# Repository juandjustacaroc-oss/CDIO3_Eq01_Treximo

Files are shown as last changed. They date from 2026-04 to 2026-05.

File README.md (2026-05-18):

# CDIO3_Eq01_Treximo: Smart Athletic Timing & Physiological Monitoring System
Sistema distribuido basado en ESP32 para cronometraje automático y monitoreo fisiológico en pruebas de atletismo (100 m), diseñado para proporcionar mediciones precisas de tiempo, velocidad y frecuencia cardíaca en tiempo real. Este proyecto integra comunicación inalámbrica de baja latencia, procesamiento embebido y una interfaz web ligera para ofrecer retroalimentación inmediata al entrenador sin depender de infraestructura externa o servicios en la nube.



# Objetivo del Proyecto
Desarrollar un sistema portátil y autónomo capaz de:
- Detectar automáticamente el inicio y finalización de la carrera.
- Calcular el tiempo exacto del recorrido.
- Estimar la velocidad promedio del atleta.
- Monitorear la frecuencia cardíaca durante la carrera y la fase de recuperación.
- Visualizar métricas en pantalla OLED y en una interfaz web básica embebida.
- Reiniciar el sistema de forma segura para múltiples sesiones consecutivas.

# Arquitectura General
- Peon Salida/Peon Llegada.
- Cerebro Cronometro.
- Banda de variables fisiologicas.
La comunicación entre nodos se realiza mediante ESP-NOW.
El nodo central también opera como punto de acceso WiFi para permitir la visualización de datos desde un smartphone o tablet.

# Estado Actual [MAHD](https://docs.google.com/spreadsheets/d/1o7weHOlPSlPQWPbzmIAxRxXA6ihxt1Q-x_elVm5SotQ/edit?usp=sharing) 
- ✅Hardware funcional
- ✅Comunicación estable entre nodos
- ✅Cronometría precisa basada en eventos
- ❌Monitoreo cardíaco integrado
- ✅Interfaz TFT operativa
- ✅Dashboard web ligero en pruebas

# Librerías necesarias

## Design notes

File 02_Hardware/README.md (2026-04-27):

# Hardware

## Diseño y Arquitectura Física del Sistema

Esta carpeta contiene todos los recursos asociados al desarrollo físico y electrónico del sistema distribuido basado en ESP32.

El hardware está dividido en tres subsistemas principales:

- 🧠 Cronómetro Central
- 📡 Peones (Salida y Llegada)
- ❤️ Banda de Variables Fisiológicas

---

## Estructura de Carpetas

### 📂 Datasheets/
Contiene únicamente hojas técnicas oficiales (PDF) de los componentes utilizados:
- ESP32
- UWB (DW1000 / RYUW122)
- MAX3010x
- RTC
- Pantalla TFT
- Módulos de carga
- Sensores ultrasónicos

Estos documentos fundamentan las decisiones técnicas adoptadas en el diseño.

---

### 📂 Mechanical/
Archivos mecánicos del proyecto:
- STL (impresión 3D)
- DXF (corte láser)
- CAD (modelos completos)

Incluye:
- Carcasa del cronómetro
- Soportes de peones
- Integración de banda fisiológica

---

### 📂 Source/
Archivos editables de diseño electrónico:
- KiCad
- Altium
- Eagle

Contiene:
- Esquemáticos
- PCB
- Layout
- Gerbers (si aplica)

---

## Consideraciones Técnicas

- Alimentación autónoma con sistema de carga y protección.
- Comunicación inalámbrica UWB para medición de distancia.
- ESP-NOW para eventos críticos de cronometraje.
- Diseño modular para mantenimiento y escalabilidad.

---

## Estado

El hardware ha sido auditado y actualizado tras la revisión técnica del diseño inicial.
Las modificaciones están justificadas en la Matriz de Defensa de Diseño (ver carpeta 01_Gestion).

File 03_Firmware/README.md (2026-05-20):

# 03_Firmware — Firmware ESP32 TRÉXIMO

Esta carpeta contiene el firmware de los nodos ESP32 que conforman el sistema **TRÉXIMO**.

El firmware implementa:
- detección de eventos,
- cronometraje,
- comunicación inalámbrica,
- cálculo de variables deportivas,
- integración con la aplicación web,
- y gestión de estados del sistema.

---

# Nodos del sistema

| Nodo | Función | Archivo esperado |
|---|---|---|
| Cerebro / Cronómetro | Recibe eventos, calcula tiempo y velocidad, y envía datos a la aplicación | `CerebroFinal_*.ino` |
| Peón salida | Detecta salida mediante HC-SR04 y envía evento `START` | `Peon_Salida_*.ino` |
| Peón llegada | Detecta llegada mediante HC-SR04 y envía evento `FINISH` | `Peon_Llegada_*.ino` |
| Simulador ESP32 | Genera carreras aleatorias para pruebas de backend/app | `ESP32_Treximo_Simulador_*.ino` |
| Banda HR | Evaluada durante desarrollo; retirada del PMV | SIN ARCHIVO |

---

# Arquitectura de firmware

```text
Peón salida ── MSG_START ┐
                         ├── Cerebro FSM ── WiFi POST ── App web
Peón llegada ─ MSG_FINISH┘

UWB TAG/ANCHOR ─ distancia
```

---

# Máquina de estados del cerebro

| Estado | Descripción | Evento de salida |
|---|---|---|
| `IDLE` | Espera carrera o calibración | START manual o `MSG_START` |
| `CALIBRATING` | Solicita y espera distancia UWB | `MSG_DISTANCE` o timeout |
| `RUN` | Cronómetro en carrera | STOP manual o `MSG_FINISH` |
| `RECOVERY` | Tiempo de recuperación entre carreras | Timeout de 60 s |
| `UPLOAD` | Envía datos al backend local | HTTP OK/Error |
| `ERROR` | Estado de fallo controlado | Reset manual |

---

# Librerías necesarias

## Librerías incluidas con Arduino / ESP32

```cpp
#include <WiFi.h>
#include <esp_now.h>
#include <esp_wifi.h>
#include <HTTPClient.h>
#include <WiFiClient.h>
#include <Preferences.h>
#include <SPI.h>
#include <Wire.h>
#include <time.h>
```

---

## Librerías externas

Instalar desde Library Manager o mediante ZIP, también se encuentran alojadas en el repositorio.

| Librería | Uso |
|---|---|
| `Adafruit_GFX` | Gráficos TFT |
| `Adafruit_ST7735` | Pantalla TFT ST7735 |
| `RTClib` | RTC DS3231 |
| `DW1000Ranging` | Comunicación UWB |
| `ArduinoJson` | Manejo de estructuras JSON |
| `MAX30105` | Histórico del sensor cardíaco |

---

# Configuración de placa

- Placa: `ESP32 Dev Module`
- Velocidad Serial: `115200`
- WiFi: `2.4 GHz`
- Canal ESP-NOW: igual para todos los nodos
- Flash: configuración estándar Arduino IDE

---

# Pines principales

## Cerebro

| Elemento | Pin |
|---|---|
| TFT SCK | GPIO18 |
| TFT MOSI | GPIO23 |
| TFT CS | GPIO5 |
| TFT DC | GPIO2 |
| TFT RST | GPIO4 |
| RTC SDA | GPIO21 |
| RTC SCL | GPIO22 |
| START | GPIO12 |
| STOP | GPIO13 |
| RESET | GPIO14 |

---

## Peones

| Elemento | Pin |
|---|---|
| HC-SR04 TRIG | GPIO15 |
| HC-SR04 ECHO | GPIO2 |
| LED | GPIO16 |
| UWB SCK | GPIO18 |
| UWB MISO | GPIO19 |
| UWB MOSI | GPIO23 |
| UWB CS | GPIO4 |
| UWB RST | GPIO27 |
| UWB IRQ | GPIO34 |

---

# Variables de configuración

```cpp
const char* WIFI_SSID = "TU_WIFI";
const char* WIFI_PASS = "TU_CLAVE";

const char* API_URL =
"http://IP_DEL_PC:8081/api/ingest-workout";

const char* DEVICE_TOKEN =
"treximo-secret-123";
```

---

# Reglas de desarrollo

- Evitar `delay()` en tareas críticas.
- Utilizar temporizadores o interrupciones cuando sea necesario.
- Mantener callbacks ESP-NOW ligeros.
- Guardar configuraciones persistentes mediante `Preferences`.
- Reportar errores por Serial y/o pantalla TFT.
- No subir credenciales reales a repositorios públicos.

---

# Flujo mínimo de prueba

1. Cargar firmware en peón de salida.
2. Cargar firmware en peón de llegada.
3. Cargar firmware en cerebro central.
4. Verificar recepción de `START` y `FINISH`.
5. Ejecutar calibración de distancia.
6. Ejecutar carrera de prueba.
7. Verificar envío HTTP al backend.
8. Confirmar visualización en la aplicación.

---

# Estado actual del firmware

| Subsistema | Estado | Observaciones |
|---|---|---|
| Comunicación ESP-NOW | Validado | Comunicación estable entre nodos |
| HC-SR04 | Parcial | Requiere calibración en exteriores |
| UWB | Parcial | Error variable en medición |
| RTC | Validado | Registro temporal estable |
| Interfaz TFT | Validado | Visualización funcional |
| Frecuencia cardíaca | Retirada del PMV | Lectura inestable y sensor dañado |

---

# Objetivo del firmware

El firmware de TRÉXIMO busca garantizar:
- sincronización entre nodos,
- medición precisa de eventos deportivos,
- portabilidad,
- integración con sistemas digitales,
- y trazabilidad del rendimiento deportivo en tiempo real.

---

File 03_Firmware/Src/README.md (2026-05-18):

# Contenido

Pruebas Individuales

  - UWB 
  https://how2electronics.com/getting-started-with-esp32-dw1000-uwb-ultra-wideband-module/#google_vignette
  - HCSR04
  - MAX30102
  - ESP-NOW
  - Extraer Dirección MAC ESP32
  - Prueba de Interfaz
  - 
  
Subsistemas
  - Banda
  - Peón Salida/Llegada
  - Cronómetro

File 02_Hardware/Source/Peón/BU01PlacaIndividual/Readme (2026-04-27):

PCB de BU01 para conexión como modulo adicional

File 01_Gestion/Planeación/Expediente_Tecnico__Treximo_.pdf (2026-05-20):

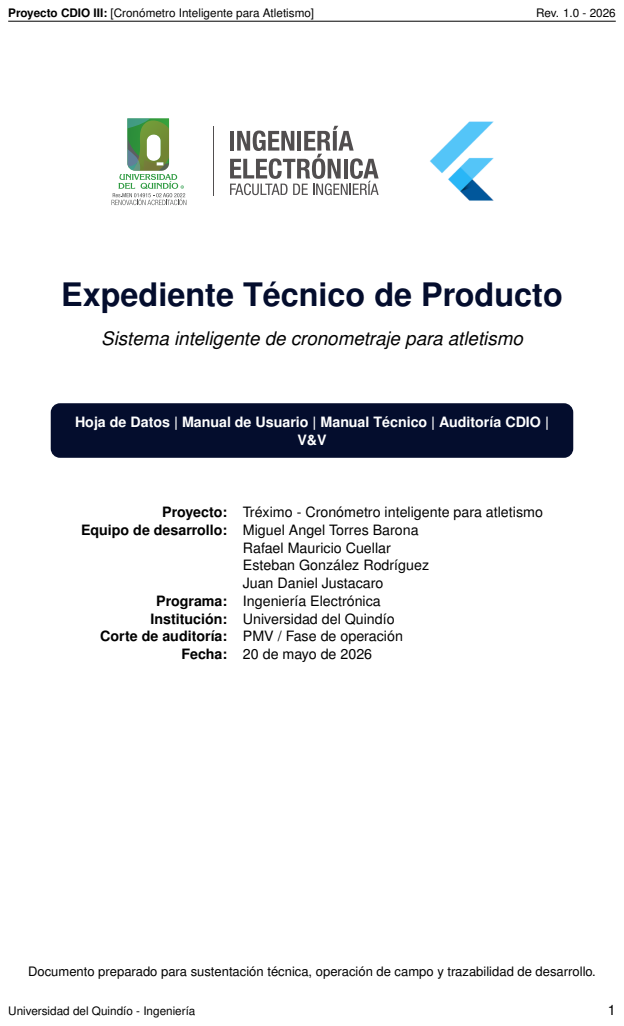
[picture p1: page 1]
Proyecto CDIO III: [Cronómetro Inteligente para Atletismo]; Rev. 1.0 - 2026; Universidad del Quindío - Ingeniería

Expediente Técnico de Producto

Sistema inteligente de cronometraje para atletismo

Hoja de Datos | Manual de Usuario | Manual Técnico | Auditoría CDIO

Proyecto: Tréximo - Cronómetro inteligente para atletismo

Equipo de desarrollo: Miguel Angel Torres Barona

Rafael Mauricio Cuellar
Esteban González Rodríguez
Juan Daniel Justacaro

Programa: Ingeniería Electrónica
Institución: Universidad del Quindío

Corte de auditoría: PMV / Fase de operación

Fecha: 20 de mayo de 2026

Documento preparado para sustentación técnica, operación de campo y trazabilidad de desarrollo.

## Índice

1. Resumen Ejecutivo | 3
2. Hoja de Datos del Sistema | 3
3. Arquitectura del Sistema | 4
4. Estado de Cumplimiento ON-Ramp | 7
5. Resultados de Verificación y Validación (V&V) | 8
6. Manual de Usuario | 8
7. Manual Técnico | 9
8. BOM y Auditoría Financiera | 13
9. Desempeño Operativo MAHD/IPAC | 14
10.Roadmap Final | 15
11.Anexos y Evidencia Técnica | 15

## 1 Resumen Ejecutivo

El proyecto se encuentra en estado AMARILLO CONTROLADO: el Producto Mínimo Viable realiza cronometraje automático con peón de salida, peón de llegada, comunicación ESP-NOW, calibración de distancia UWB, visualización en pantalla TFT y transmisión de resultados a una interfaz web local mediante API HTTP. Las pruebas reportan autonomía mayor a 2 horas en el cronómetro, comunicación ESP-NOW menor a 10 ms hasta 20 m, medición UWB hasta 20 m y validación funcional de transmisión hacia la interfaz. La principal desviación técnica es la frecuencia cardiaca: el MAX30102 fue estable en dedo, pero inestable en muñeca, por lo que se retiró como medición real del PMV y se reemplazó por un valor fijo para la demostración. La arquitectura final prioriza estabilidad: los peones operan por ESP-NOW, el cerebro procesa tiempo/distancia/velocidad y la app Flutter con backend local almacena sesiones para análisis del entrenador.

## 2 Hoja de Datos del Sistema

### 2.1 Descripción general

Tréximo es un sistema de cronometraje inteligente para pruebas de atletismo. Está compuesto por un nodo central o cerebro, un peón de salida, un peón de llegada y una interfaz web de consulta. El sistema automatiza la detección de salida y llegada, calcula duración, distancia y velocidad, y almacena las sesiones en una app local para revisión posterior del entrenador.

### 2.2 Capacidades del PMV

Cronometraje automático por detección ultrasónica en salida y llegada.

Comunicación inalámbrica entre peones y cerebro mediante ESP-NOW.

Medición/calibración de distancia con módulos UWB BU01 basados en DW1000.

Cálculo de velocidad en m/s a partir de distancia calibrada y tiempo de carrera.

Operación manual con botones START, STOP y RESET en el cerebro.

Pantalla TFT para estado de carrera, tiempo, distancia, velocidad y BPM fijo de demostración.

Envío de entrenamientos por WiFi a backend local Dart Shelf en puerto 8081.

Visualización web Flutter para atletas, historial y sesiones recientes.

### 2.3 Límites técnicos y supuestos

El sistema no es sumergible ni está certificado para lluvia intensa.

El desempeño del HC-SR04 depende de alineación, ángulo y altura de instalación.

La frecuencia cardiaca real no queda incluida en el PMV por inestabilidad del sensor en muñeca.

La subida a la app ocurre al final de la sesión, evitando interferir con ESP-NOW durante la carrera.

La interfaz local requiere que ESP32, backend y dispositivo del entrenador estén en la misma red WiFi.

### 2.4 Especificaciones técnicas consolidadas

Tabla 1: Especificaciones del PMV Tréximo

Parámetro | Descripción | Valor / Estado
Microcontrolador | Nodo central y peones | ESP32-WROOM
Pantalla | Visualización local del cronómetro | TFT SPI 1.77” 160x128
Reloj | Registro temporal local | RTC DS3231
Detección de cruce | Peones salida/llegada | HC-SR04 con interrupciones
Umbral ultrasónico | Distancia validada para detección | 50 cm
Ángulo recomendado | Zona de detección del atleta | 0° a 22.5°
Altura recomendada | Posición de peones | Altura de cadera
Comunicación peones | Eventos START/FINISH | ESP-NOW
Latencia ESP-NOW | Prueba de comunicación | < 10 ms
Alcance probado ESP-NOW Campo de prueba | 20 m
Medición distancia | UWB ToF | BU01/DW1000
Alcance probado UWB | Distancia máxima validada | 20 m
Velocidad | Cálculo operativo | v = d/t en m/s
BPM | PMV actual | Valor fijo configurable
Backend local | Recepción de datos | Dart Shelf + SQLite, puerto 8081
Interfaz | Dashboard entrenador | Flutter Web, puerto 3000
Autonomía cronómetro | Prueba funcional | Mayor a 2 h

## 3 Arquitectura del Sistema

### 3.1 Arquitectura funcional

Flujo general de operación

Peón de salida HC − SR04 + UW BT ag → ESP − NOW ST ART→ CerebroESP32 Peón de llegada HC −SR04 +UW BAnchor → ESP − NOW F INISH→ CerebroESP32 Cerebro ESP32 → W iF iHT T P P OST → Backendlocal → SQLite → FlutterW eb

### 3.2 Evidencia visual del prototipo físico

Las siguientes imágenes documentan el estado físico del PMV. Se recomienda mantenerlas en el expediente porque permiten relacionar la arquitectura descrita con el montaje real usado en pruebas de campo.

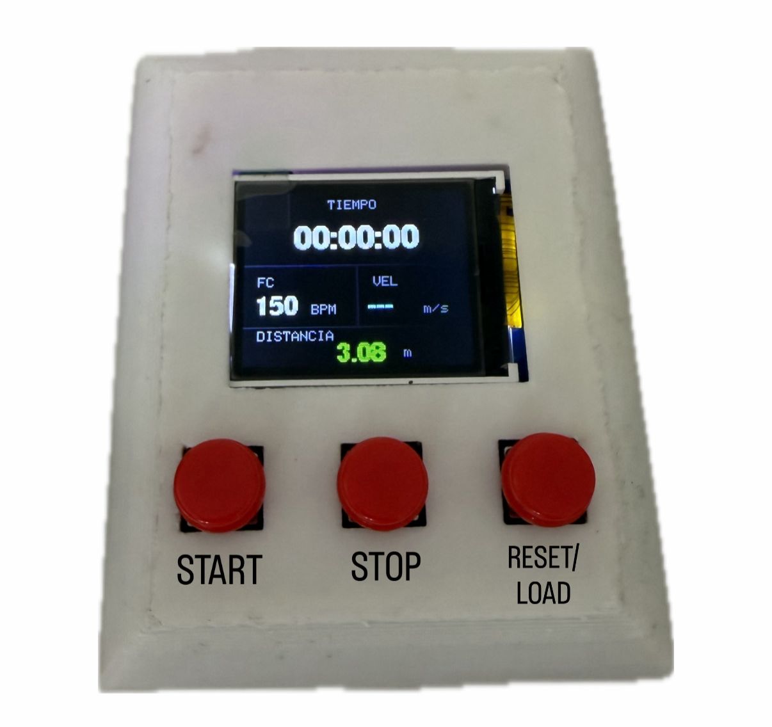
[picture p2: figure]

Figura 1: Vista frontal del cronómetro/cerebro Tréximo. Este módulo integra pantalla TFT, botones de operación, RTC, comunicación ESP-NOW y transmisión WiFi hacia la app.

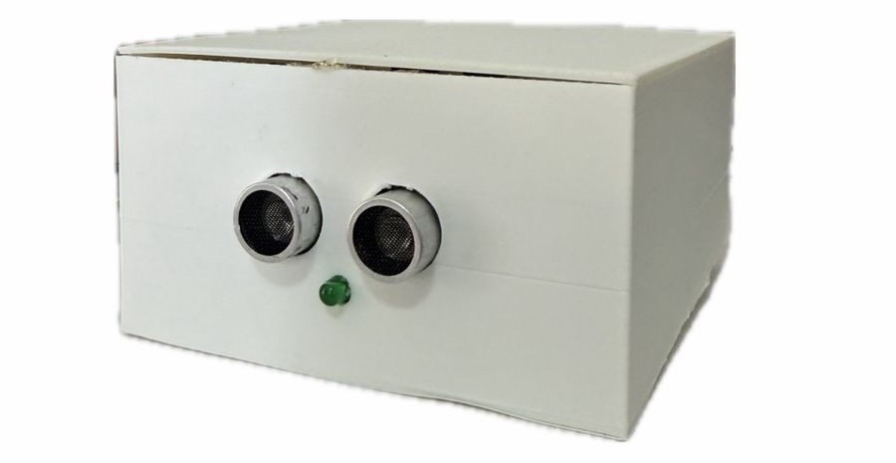
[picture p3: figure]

Figura 2: Conjunto de peones de salida y llegada. Ambos usan la misma lógica de ultrasonido y LED; se diferencian por el rol lógico enviado al cerebro: START o FINISH.

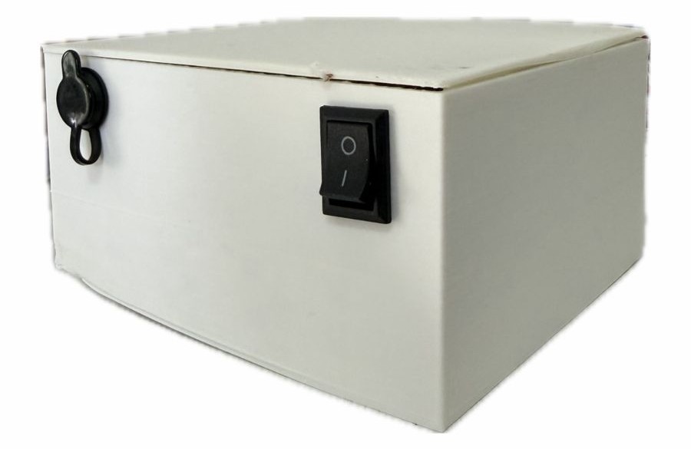
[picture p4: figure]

Figura 3: *
Peón de salida: HC-SR04 + LED + UWB Tag.

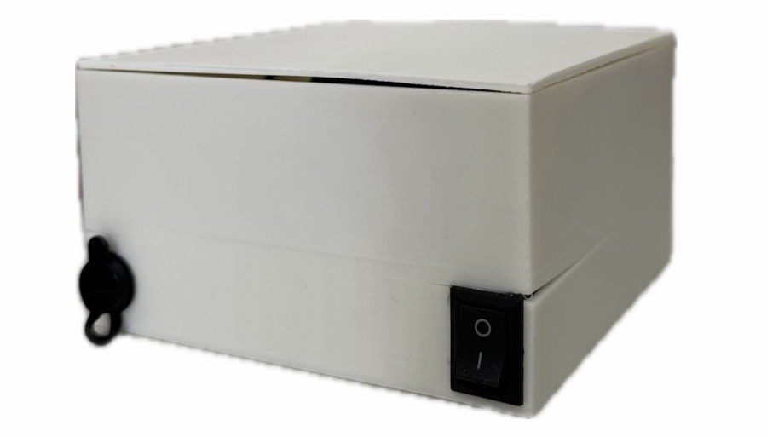
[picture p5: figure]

Figura 4: *
Peón de llegada: HC-SR04 + LED + UWB Anchor.

Figura 5: Detalle de los peones utilizados para detectar el paso del atleta y transmitir eventos al cerebro por ESP-NOW.

### 3.3 Subsistemas

Tabla 2: Subsistemas del PMV
Subsistema | Componentes | Función
Cerebro | ESP32, TFT, RTC DS3231, botones, WiFi | Recibe eventos, cronometra, calcula velocidad, muestra estado y sube datos.
Peón salida | ESP32, HC-SR04, BU01 UWB Tag, LED | Detecta atleta en salida y envía MSG_START.

Peón llegada ESP32, HC-SR04, BU01 UWB Anchor,
| LED | Detecta atleta en llegada y envía MSG_FINISH.
Interfaz web | Flutter Web + backend Dart Shelf + SQLite | Almacena y presenta atletas, sesiones e historial.
BPM | MAX30102 retirado del PMV | Se reemplaza por valor fijo para demostración por inestabilidad en muñeca.

### 3.4 Formato de datos enviado a la app

Listing 1: Payload HTTP del ESP32 hacia el backend local

{
" device_id ": " treximo -001" ,
" device_type ": " treximo_esp32 " ,
" race_id ": 23 ,
" athlete_code ": 1 ,
" start_time ": "2026 -05 -13 T15 :20:10 -05:00" , " finish_time ": "2026 -05 -13 T15 :20:18 -05:00" , " duration_ms ": 8230 ,
" distance_m ": 50.0 ,
" speed_mps ": 6.07 ,
" bpm_finish ": 150 ,

" bpm_recovery_60s ": 150 ,
" distance_calibrated ": true ,
" firmware ": " CerebroFinal_WebAPI_v4_3_BPM_FIJO " }

## 4 Estado de Cumplimiento ON-Ramp

Tabla 3: Trazabilidad de requisitos contra PMV actual

ID | Requisito / Promesa | Estado | Observación técnica

REQ-01 Cronometrar automáticamente una
| carrera con salida y llegada.

Logrado Peones transmiten START/FINISH
| | | por ESP-NOW al cerebro.
REQ-02 Medir distancia real entre peones. | Logrado UWB BU01 validado hasta 20 m y
| | | usado para calibración.
REQ-03 Calcular velocidad del atleta. | Logrado Velocidad calculada en m/s con
| | | distancia calibrada y tiempo.
REQ-04 Mostrar resultados en pantalla
| local.

Logrado TFT muestra estado, tiempo,
| | | distancia, velocidad y BPM fijo.
REQ-05 Registrar sesiones en app/web. | Logrado Backend local recibe POST y la app
| | | Flutter muestra entrenamientos.
REQ-06 Medir frecuencia cardiaca real. | Parcial | MAX30102 estable en dedo,
| | | inestable en muñeca; se usa BPM fijo en PMV.

REQ-07 Operar sin sensores externos si se
| requiere.

Logrado Botones START/STOP/RESET
| | | permiten operación manual.
REQ-08 Alimentación portátil. | Logrado Cronómetro superó 2 h de
| | | autonomía.

## 5 Resultados de Verificación y Validación (V&V)

Tabla 4: Resumen de pruebas unitarias e integración

ID | Parámetro evaluado | Resultado | Dato registrado / causa raíz

PRB-1.0 Duración de baterías en

| cronómetro | Logrado | Autonomía mayor a 2 h con descarga mínima observada.
PRB-1.1 Elevador DC-DC XL6009 | Logrado | Aprobó con baterías Li-ion 3.7
| | | V,
PRB-2 | Continuidad y soldaduras de PCB | Logrado | Continuidad verificada con multímetro; sin cortos reportados.
PRB-3.0 HC-SR04 individual | Logrado | Sensor cumple función de
| | | detección del atleta con firmware adecuado.

PRB-3.1 Ángulo y posición de
| ultrasonido | Logrado | Ubicación a altura de cadera, umbral 50 cm y ángulo 0° a 22.5°.
PRB-4.0 Medición de distancia UWB | Logrado | Medición máxima validada de
| | | 20 m, suficiente para prueba de campo.
PRB-5 | ESP-NOW: latencia y alcance | Logrado | Latencia menor a 10 ms y operación adecuada a 20 m.
PRB-6 | RTC DS3231 | Logrado | Integrado al cerebro; se recomienda contraste final con patrón externo.
PRB-7 | MAX30102 | Pendiente/Fallo Estable en dedo; inestable en
| | | muñeca. Retirado del PMV operativo.
PRB-8 | Transmisión a interfaz | Logrado | Backend/API y Flutter Web reciben y muestran sesiones.

### 5.1 Criterio de aceptación del PMV

El PMV se acepta si el sistema detecta salida y llegada, calcula tiempo y velocidad, permite calibrar distancia, conserva operación manual y sube una sesión al backend local visible en la app. Bajo este criterio, el sistema es funcional para demostración técnica y prueba de campo controlada. La medición cardiaca real queda excluida del alcance de esta versión.

## 6 Manual de Usuario

### 6.1 Inicio rápido en campo

1. Encender el cerebro, peón de salida y peón de llegada.
2. Verificar que los peones estén alineados a la altura de la cadera.
3. Iniciar backend local en el computador: dart run bin/server.dart con puerto 8081.
4. Iniciar la app Flutter Web en puerto 3000 y activar modo API local.

5. Calibrar distancia desde el cronómetro con STOP + RESET.
6. Ubicar atleta en salida; el peón de salida envía START automáticamente.
7. El peón de llegada envía FINISH cuando detecta el cruce.
8. El cerebro calcula velocidad, muestra resultado y envía la sesión a la app.
9. El entrenador revisa historial, atleta y desempeño en la interfaz web.

### 6.2 Operación manual

Si no se desean usar peones, el entrenador puede usar los botones del cerebro:

START: iniciar cronómetro.

STOP: detener cronómetro.

RESET: reiniciar cronómetro.

STOP + RESET: calibrar distancia UWB.

### 6.3 Solución rápida de problemas

Tabla 5: Troubleshooting operativo

Síntoma | Acción recomendada
No aparece sesión en app | Confirmar backend en 192.168.20.21:8081, app en modo API y refrescar dashboard.
ESP32 muestra error APP | Verificar WiFi, IP del computador, puerto 8081 y firewall de Windows.
Peón detecta aleatoriamente | Revisar alineación, altura de cadera, umbral 50 cm y estabilidad de alimentación.
UWB no calibra | Verificar que salida sea Tag, llegada Anchor y ambos tengan alimentación estable.
BPM no cambia | Es esperado en PMV: el valor es fijo por retiro del MAX30102.

## 7 Manual Técnico

### 7.1 Teoría de operación

El sistema opera con una máquina de estados en el cerebro. En reposo espera eventos de peones o botones. Al recibir START registra el tiempo inicial. Al recibir FINISH registra tiempo final, calcula duración y velocidad. Finalizada la sesión, el cerebro se conecta por WiFi al backend local y envía el JSON del entrenamiento. Esta separación evita que WiFi interfiera con ESP-NOW durante la carrera.

### 7.2 Máquina de estados del firmware

La máquina de estados organiza el comportamiento del cronómetro para evitar condiciones de carrera entre ESP-NOW, UWB, pantalla, botones y WiFi. La regla de diseño más importante es que durante la carrera el sistema prioriza eventos críticos de tiempo y evita tareas de red WiFi; la subida a la app se ejecuta después de finalizar la medición.

Tabla 6: Estados principales del cerebro Tréximo

Estado | Función | Transición principal
IDLE | Sistema en espera. Muestra información base, acepta botones y puede calibrar distancia. | Recibe START manual o MSG_START del peón de salida.
CALIBRANDO | Solicita medición UWB, toma/promedia muestras y guarda distancia calibrada. | Combinación STOP + RESET; vuelve a IDLE con distancia o error UWB.
RUN | Cronómetro activo. Se actualiza pantalla y se espera llegada. | Recibe STOP manual o MSG_FINISH del peón de llegada.
RECOVERY | Ventana posterior a carrera para registrar valor de recuperación. En el PMV se usa BPM fijo. | Termina el minuto de recuperación.
UPLOAD | Genera JSON, conecta WiFi y envía POST /api/ingest-workout.

Si HTTP 2xx: muestra APP OK; si falla: conserva pendiente y reintenta.

Racional de la máquina de estados

La separación de estados reduce errores: el cronómetro no calibra durante una carrera, no sube datos mientras espera FINISH y no depende de la app para completar una medición. Esto permitió estabilizar el PMV cuando se integraron peones, UWB, botones, pantalla TFT y backend web.

### 7.3 Arquitectura de firmware y flujo lógico

El diagrama de flujo de la Figura 6 resume el ciclo principal: inicialización, espera, calibración, carrera, recuperación y subida de datos a la interfaz.

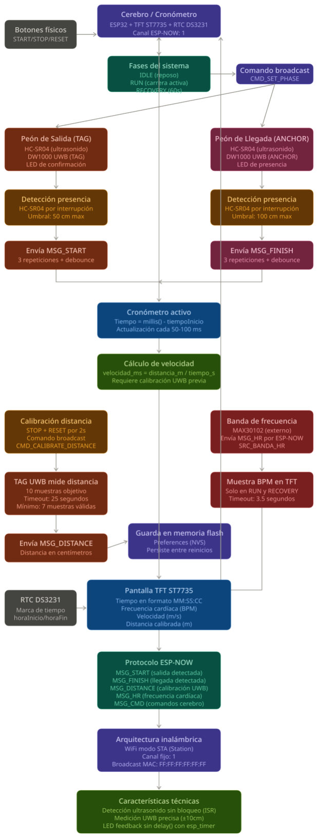
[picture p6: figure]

Figura 6: Diagrama de flujo del firmware del sistema Tréximo. Esta figura debe ubicarse exclusivamente en la sección de arquitectura de firmware.

### 7.4 Decisiones de diseño relevantes

ESP-NOW sobre NRF24L01: se eligió por simplicidad, menor cableado y menor latencia observada.

UWB sobre GPS: se seleccionó UWB para medir distancias cortas de pista con mayor pertinencia que GPS NEO-6M.

Interfaz separada del ESP32: se evitó alojar dashboards complejos en el microcontrolador por limitaciones de memoria.

Interrupciones en HC-SR04: se sustituyeron rutinas bloqueantes para reducir latencia e interferencia con UWB/ESP-NOW.

BPM fijo en PMV: se priorizó la confiabilidad del cronometraje ante inestabilidad fisiológica en muñeca.

### 7.5 Pinout funcional resumido

Tabla 7: Conectividad principal usada en prototipo

Módulo | Señal | Pin / Observación
Peones | HC-SR04 TRIG/ECHO | TRIG GPIO15, ECHO GPIO2
Peones | LED estado | GPIO16
UWB BU01 SPI | SCK 18, MISO 19, MOSI 23, CS 4
UWB BU01 Control | RST 27, IRQ 34
Cerebro | Botones | START 12, STOP 13, RESET 14
Cerebro | RTC DS3231 | I2C
Cerebro | Pantalla TFT | SPI según montaje del prototipo

### 7.6 Esquemáticos electrónicos del prototipo

Los esquemáticos se incluyen como evidencia técnica del diseño as-built. Overleaf puede mostrar directamente archivos .png, .jpg, .jpeg y .pdf; para archivos .svg se recomienda convertirlos previamente a PNG o PDF para evitar problemas de compilación.

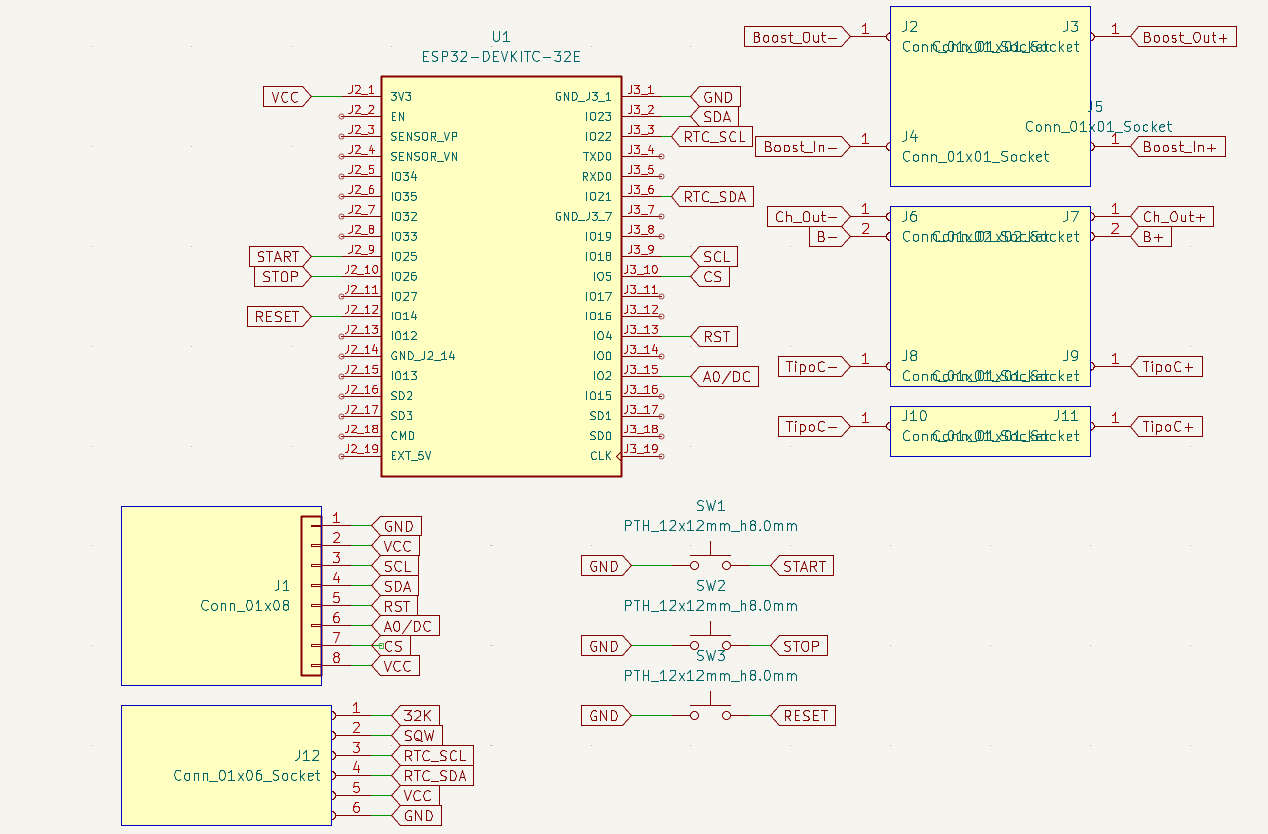
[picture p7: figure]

Figura 7: Esquemático del módulo cerebro: ESP32 central, pantalla, RTC, botones y conexiones principales.

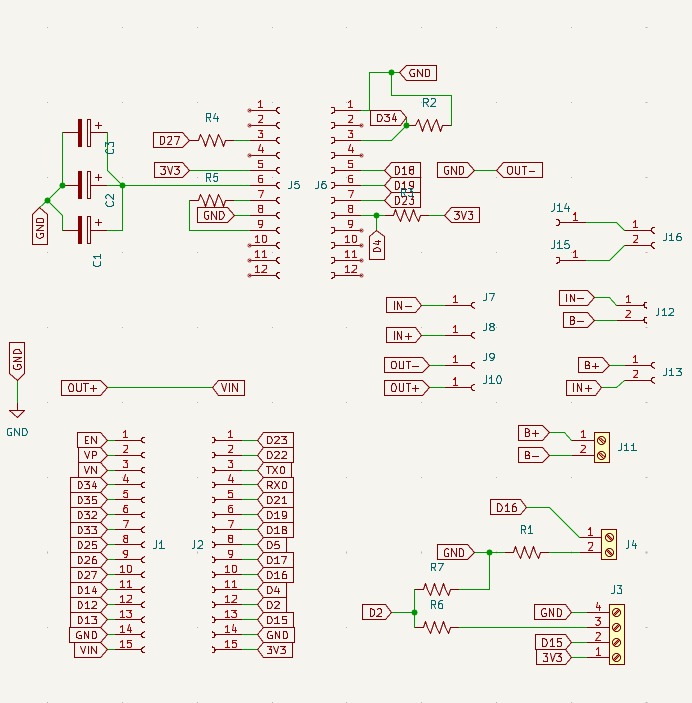
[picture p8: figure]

Figura 8: Esquemático base del peón: ESP32, HC-SR04, LED indicador y módulo UWB. La misma base se usa para salida y llegada; cambia el rol lógico del firmware.

## 8 BOM y Auditoría Financiera

### 8.1 BOM ejecutado

Tabla 8: Lista de materiales principal

ID | Cant. Componente | Uso
U1 | 3-4 | ESP32-WROOM | Cerebro, peones y pruebas de módulo independiente.
S1 | 2 | HC-SR04 | Detección de salida y llegada.
M1 | 2 | BU01/DW1000 UWB | Medición de distancia entre peones.
P1 | 1 | TFT SPI 1.77” | Interfaz local del cronómetro.
M2 | 1 | RTC DS3231 | Marca temporal del sistema.
B1 | 4 | Celdas 18650 | Alimentación portátil.
M3 | 2 | TP4056 / gestión de carga Carga de baterías Li-ion.
S2 | 1 | MAX30102 | Sensor evaluado; no incluido en PMV final.
L1 | 2+ | LEDs | Indicadores de peones.
SW | 3+ | Push buttons | Control manual y calibración.

### 8.2 Control financiero

No se adjuntó una tabla de facturación consolidada con valores finales por componente. Por tanto, la auditoría financiera se deja como pendiente de cierre cuantitativo; sin embargo, el BOM ejecutado permite organizar facturas por subsistema y calcular el Costo Variable Unitario (CVU) antes de la entrega final.

## 9 Desempeño Operativo MAHD/IPAC

### 9.1 Lecciones aprendidas consolidadas

Tabla 9: Síntesis de lecciones IPAC

Ciclo | Lección principal | Acción correctiva
IPAC 1-2 | La falta de arquitectura documenta-
da genera retrabajo; el ultrasonido solo no era suficiente para distancia.
| | | Repositorio formal, separación de módulos, adopción de UWB y ESP- NOW.
IPAC 3 | El diseño mecánico debe estabilizar-
se después de definir electrónica y
| | baterías. | Rediseño de carcasas, soportes in- ternos y distribución de componen- tes.
IPAC 4 | Los delays y páginas web complejas
en ESP32 generan inestabilidad.
| | | Temporizadores con millis(), inter- faz web separada y JSON optimiza- do.
IPAC 5 | MAC incorrectas, canal WiFi y ener-
| | gía afectan ESP-NOW. | Lectura de MAC, canal fijo y revisión de alimentación antes de conexión.
IPAC 6 | La integración revela errores no visi-
bles en pruebas unitarias.
| | | Máquina de estados, callbacks opti- mizados y desacople de módulos.
IPAC 7 | La visualización frecuente puede sa-
turar memoria si no se separa arqui-
| | tectura. | Backend/API local y frontend Flutter externo al microcontrolador.

Ciclo | Lección principal | Acción correctiva
IPAC 8 | Campo real introduce ruido, obstácu-
| los y sensibilidad de alineación. | Recalibración, umbrales ultrasónicos
| | y eliminación de HR real del PMV.
IPAC 9 | Documentar continuamente reduce
| carga de cierre. | Consolidación de dossier, README,
| | evidencias y pruebas.

### 9.2 Cuellos de botella técnicos

Frecuencia cardiaca: el MAX30102 no fue confiable en muñeca; se reemplaza temporalmente por BPM fijo.

Interfaz en ESP32: se migró a app Flutter/backend local para evitar saturación del microcontrolador.

Detección de llegada: se homologó la lógica del peón de llegada con el peón de salida para evitar disparos aleatorios.

WiFi/API: se estandarizó backend en puerto 8081 y app web en puerto 3000 para pruebas de campo.

## 10 Roadmap Final

1. Validar cronometraje completo con dos o más recorridos reales por atleta.
2. Realizar medición manual de referencia para comparar error de tiempo y velocidad.
3. Consolidar facturas y cerrar CVU real del prototipo.
4. Agregar botón de refresco o auto-refresh en dashboard si no actualiza sesiones en vivo.
5. Reemplazar BPM fijo por alternativa fisiológica más confiable para muñeca o banda de pecho.
6. Documentar procedimiento de calibración y montaje con fotografías finales.

## 11 Anexos y Evidencia Técnica

### 11.1 Anexo A - Evidencia de pruebas

La bitácora de pruebas incluye evidencia fotográfica de autonomía del cronómetro, pruebas de elevador DC-DC, continuidad de PCB, montaje de peón ultrasónico y validación de transmisión a interfaz web. Para la entrega final se recomienda insertar las imágenes más nítidas de esa bitácora y referenciarlas contra la Tabla de V&V.

### 11.2 Anexo B - Interfaz web y mapa de navegación

El archivo ux_navigation_map.svg corresponde al mapa de navegación de la interfaz web. Para incluirlo gráficamente en Overleaf se recomienda exportarlo como ux_navigation_map.png o ux_navigation_map.pdf. No se ubica en la sección de firmware para mantener separado el flujo del microcontrolador y la navegación de la app.

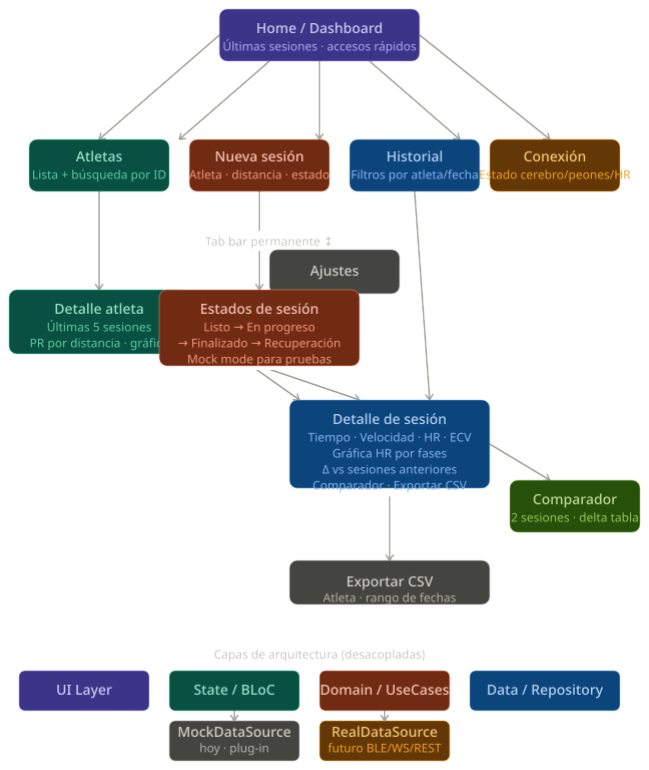
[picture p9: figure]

Figura 9: Mapa de navegación de la interfaz Tréximo. Este anexo apoya la descripción de la app, pero no reemplaza el diagrama de flujo del firmware.

### 11.3 Anexo C - Comandos de prueba de campo

Listing 2: Comandos de operación local cd / d C : \ Users \ Migue \ Downloads \ f l u t t e r \ Projects \ s p r i n t _ t i m e r \ server set PORT=8081
dart run bin / server . dart

cd / d C : \ Users \ Migue \ Downloads \ f l u t t e r \ Projects \ s p r i n t _ t i m e r
f l u t t e r run −d web−server −−web−hostname 0 . 0 . 0 . 0 −−web− port 3000

### 11.4 Anexo D - Configuración ESP32 para API

Listing 3: Variables principales del firmware const char

* WIFI_SSID = " SSID_WIFI " ; const char

* WIFI_PASS = "CLAVE_WIFI " ;
const char

* API_URL = " h t t p : // 1 9 2 .1 6 8 . 20 . 2 1: 8 0 8 1/ api / ingest −workout " ; const char

* DEVICE_TOKEN = " treximo −secret −123";
# define FIXED_BPM_VALUE 150

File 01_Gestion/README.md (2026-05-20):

# Gestión del Proyecto — TRÉXIMO

Esta carpeta contiene la documentación de planeación, control, trazabilidad y auditoría del proyecto **TRÉXIMO: Sistema Inteligente de Cronometraje para Atletismo**.

Su propósito es evidenciar:
- La evolución del Producto Mínimo Viable (PMV).
- Las decisiones de diseño tomadas durante el desarrollo.
- La validación de subsistemas.
- La gestión técnica y organizacional del proyecto bajo metodología CDIO/IPAC.

---

# Estructura de la carpeta

```text
01_Gestion/
├── README.md
├── Auditoria.md
├── BOM/
│   └── README.md
└── Planeacion/
    ├── README.md
    ├── IPAC/
    │   └── README.md
    ├── Cronograma de actividades/
    ├── Auditoria y Planeacion/
    ├── Expediente Tecnico/
    ├── Definition_of_Done.md
    └── Protocolo_Pruebas/
        └── README.md
```

---

# Documentos principales

| Documento / Carpeta | Propósito | Estado |
|---|---|---|
| `Planeacion/README.md` | Explica la planeación general por fases CDIO/IPAC | Validado |
| `Planeacion/IPAC/README.md` | Resume ciclos IPAC, entregables, decisiones y lecciones aprendidas | Validado |
| `BOM/README.md` | Documenta costos, proveedores, desviaciones y control financiero | Validado |
| `Planeacion/Definition_of_Done.md` | Define criterios mínimos de finalización para hardware, firmware, software y documentación | Validado |
| `Planeacion/Protocolo_Pruebas/README.md` | Resume pruebas unitarias, integración, pruebas de campo y evidencia requerida | Validado |
| `Auditoria.md` | Registra hallazgos, riesgos, decisiones y trazabilidad técnica | Validado |

---

# Estado actual del PMV

| Área | Estado | Comentario |
|---|---|---|
| Cronómetro central | Funcional | Manejo de estados, pantalla TFT, botones y conexión con aplicación |
| Peones de salida/llegada | Funcional | Detección mediante ultrasonido y comunicación ESP-NOW |
| Sistema UWB | Parcial | Requiere calibración y validación de distancia real |
| Aplicación web | Funcional | Backend local y visualización mediante Flutter Web |
| Frecuencia cardiaca | Retirada del PMV | MAX30102 presentó inestabilidad en condiciones reales de uso |

---

# Criterios de gestión

Toda entrega o componente desarrollado debe incluir:

- Responsable identificado.
- Criterio de aceptación definido.
- Evidencia asociada:
  - fotografía,
  - video,
  - captura,
  - log serial,
  - commit,
  - archivo técnico.
- Relación con un requisito funcional o ciclo IPAC.
- Estado documentado.

---

# Convención de estados

| Estado | Significado |
|---|---|
| `Validado` | Probado y documentado con evidencia |
| `Parcial` | Funciona con limitaciones o bajo condiciones específicas |
| `Retirado del PMV` | Excluido de la entrega mínima por causa técnica justificada |
| `Pendiente` | No implementado o sin evidencia suficiente |
| `Requiere corrección` | Falló pruebas o necesita rediseño |

---

# Objetivo de gestión

La documentación de esta carpeta busca garantizar:
- trazabilidad técnica,
- control de cambios,
- seguimiento de requisitos,
- validación progresiva,
- y soporte para auditorías académicas y técnicas del proyecto.

---

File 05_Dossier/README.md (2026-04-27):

# Dossier

## Documentación Final y Validaciones

Esta carpeta contiene la documentación formal del proyecto en su versión consolidada.

Incluye:

- Informe técnico final
- Arquitectura del sistema
- Matriz de Defensa de Diseño (MDD)
- Validaciones experimentales
- Resultados de pruebas
- Conclusiones
- Anexos fotográficos

---

## Contenido Esperado

- Manual de usuario
- Manual técnico
- Evidencias de auditoría
- Tablas de rendimiento
- Gráficas de frecuencia cardíaca
- Comparativas de medición

---

## Propósito

Respaldar académicamente el desarrollo del proyecto bajo metodología CDIO, demostrando:

- Justificación de decisiones técnicas
- Evaluación de riesgos
- Validación experimental
- Funcionalidad operativa del sistema

Esta sección representa la evidencia formal del proyecto ante evaluación.

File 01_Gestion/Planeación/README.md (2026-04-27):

# Planeación organizada para IPAC
------
## 1. Identificación
Proyecto: Sistema de cronometraje inteligente para atletismo
Metodología: CDIO
Propósito del IPAC: Organizar y dar trazabilidad a las actividades de diseño, auditoría, validación y demostración del sistema.

## 2. Planeación por fases
### Fase 1. Planificación y auditoría

Semana 1 
Actividades:
+ Reestructuración del cronograma general.
+ Planificación detallada de pruebas unitarias por subsistema.
+ Definición de criterios de validación técnica.

Resultados esperados
* Cronograma actualizado.
* Matriz preliminar de pruebas unitarias.
* Documentación actualizada.

### Fase 2. Auditoría y consolidación de diseño
Actividades
+ Consolidación del BOM final con proveedores y estados

Resultados esperados
+ BOM final consolidado.

### Fase 3. Diseño mecánico y electrónico
Actividades
+ Diseño preliminar de esquemáticos electrónicos.
+ Diseño preliminar de modelos 3D
  
Resultados esperados
+ Modelo 3D actualizado.
+ Archivos .STL .SCH .PCB

### Fase 4. Desarrollo de software y pruebas unitarias
Actividades de diseño

+ Definición de arquitectura del firmware.

Pruebas unitarias
+ Validar protocolo I2C del sensor.
+ Validar protocolo SPI de pantalla.
+ Validar funcionamiento del sensor de presencia.
+ Validar funcionamiento del sensor de larga distancia.
+ Validar funcionamiento del sensor de frecuencia.
+ Validar funcionamiento del RTC.

Resultados esperados
+ Tramas de datos visibles en monitor serial.
+ Código funcional validado por módulo.
+ Registro fotográfico y capturas de pruebas.

### Fase 5. Validación eléctrica y comunicación
Actividades
+ Diseño preliminar de software e interfaz.
+ Pruebas del sistema de alimentación.
+ Medición de consumo bajo carga.
+ Pruebas de transmisión ESP-NOW.
+ Pruebas iniciales de medición de distancia.
+ Validación del botón de reinicio y señal a peones.

Resultados esperados
+ Primer diseño de interfaz.
+ Tabla de consumo energético.
+ Registro de transmisión inalámbrica.
+ Tabla preliminar de error en medición de distancia.

### Fase 6. Integración parcial
Semana 6

Pruebas
+ Validar funcionamiento del cronómetro (cerebro).
+ Validar funcionamiento de peones.
+ Validar transición correcta entre estados del sistema.
+ Validar cronometraje consistente en múltiples pruebas.
+ Validar funcionamiento del sistema conjunto.

Resultados esperados
+ Comportamiento visible en pantalla TFT.
+ Medición de velocidad en monitor serial.
+ Registro comparativo de tiempos.
+ Evidencia audiovisual interna.

### Fase 7. Interfaz web y transmisión de datos
Actividades
+ Validar transmisión de datos a la página web.
+ Verificar correspondencia entre pantalla TFT y navegador.
+ Optimizar el uso de memoria.
+ Realizar pruebas de actualización en tiempo real.

Resultados esperados
+ Correspondencia de datos en pantalla y página web.
+ Capturas del navegador.
+ Validación de sincronización de datos.

### Fase 8. Montaje total y correcciones
Actividades
+ Montaje total con diseños mecánicos definitivos.
+ Ajuste de alineación de sensores.
+ Pruebas reales en campo.
+ Correcciones finales del diseño.

Resultados esperados
+ Sistema completamente ensamblado.
+ Registro de pruebas en entorno real.
+ Correcciones implementadas.

### Fase 9. Demostración final
Actividades
+ Prueba completa de carrera.
+ Validación final de medición de distancia.
+ Validación de tiempo, velocidad y frecuencia cardíaca.
+ Consolidación de documentación final.

Resultados esperados
+ Demostración funcional en entorno real.
+ Dossier técnico consolidado.
+ Evidencias finales organizadas.

| Ítem | Propósito | Actividad | Criterio de aceptación | Evidencia |
| :--- | :--- | :--- | :--- | :--- |
| 1 | Reorganizar el proyecto y establecer bases técnicas claras | Reestructurar el cronograma general del proyecto | El cronograma queda actualizado, coherente y alineado con las fases del proyecto | Cronograma actualizado |
| 2 | Planificar la validación técnica del sistema | Definir pruebas unitarias por subsistema | Cada subsistema cuenta con al menos una prueba definida y un criterio de validación | Matriz preliminar de pruebas unitarias |
| 3 | Asegurar trazabilidad documental | Organizar el repositorio y la documentación | La estructura documental del proyecto queda actualizada y ordenada | Documentación organizada en repositorio |
| 4 | Fundamentar cambios sobre el diseño preliminar | Realizar auditoría técnica del diseño inicial | Se identifican hallazgos, problemas y decisiones de rediseño justificadas | Informe de auditoría técnica |
| 5 | Consolidar la defensa técnica del proyecto | Construir la Matriz de Defensa de Diseño (MDD) | Cada cambio importante del diseño queda justificado con su respectiva evidencia | MDD finalizada |
| 6 | Consolidar materiales y compras del sistema | Actualizar el BOM final con componentes, proveedores y estados | Todos los componentes relevantes se encuentran registrados en el BOM | BOM final consolidado |
| 7 | Garantizar disponibilidad de hardware | Gestionar pago y envío de los componentes faltantes | Se obtiene confirmación de compra y número de seguimiento | Tracking number recibido |
| 8 | Adaptar el diseño electrónico a los nuevos requerimientos  | Corregir el PCB para la nueva batería | El diseño actualizado permite integrar correctamente la nueva alimentación | Archivo Gerber generado y revisado |
| 9 | Ajustar el diseño físico al rediseño técnico | Corregir el modelo 3D para los nuevos diseños | El modelo mecánico refleja los cambios estructurales del sistema | Modelo 3D actualizado |
| 10 | Integrar medición de distancia al sistema | Diseñar la incorporación del módulo UWB o alternativa equivalente | El diseño contempla montaje y conexión del subsistema de distancia | Diseño actualizado del sistema |
| 11 | Validar el diseño con el cliente | Revisar requerimientos y cambios con el cliente | El cliente aprueba o retroalimenta formalmente el diseño actualizado | Registro o acta de validación con cliente |
| 12 | Definir la arquitectura lógica del sistema | Diseñar el software y la interfaz | Existe una primera propuesta funcional de firmware e interfaz | Primer diseño de interfaz |
| 13 | Validar comunicación I2C | Probar protocolo I2C del sensor correspondiente | La trama de datos es visible y coherente en monitor serial | Captura de monitor serial |
| 14 | Validar comunicación SPI | Probar protocolo SPI de pantalla | La pantalla responde correctamente a la inicialización y muestra datos | Captura de monitor serial o fotografía |
| 15 | Validar el sensor de presencia | Comprobar funcionamiento del sensor de presencia | El sensor detecta correctamente el evento esperado | Trama visible en monitor serial |
| 16 | Validar el sensor de larga distancia | Comprobar funcionamiento del sistema de medición de distancia | El sensor entrega valores consistentes y repetibles | Trama visible en monitor serial |
| 17 | Validar el sensor fisiológico | Comprobar funcionamiento del sensor de frecuencia cardíaca | El sistema detecta y muestra valores fisiológicos coherentes | Trama visible en monitor serial |
| 18 | Validar trazabilidad temporal | Comprobar funcionamiento del RTC | La fecha y hora son leídas correctamente | Trama visible en monitor serial |
| 19 | Verificar estabilidad energética del sistema | Probar el sistema de alimentación | El sistema opera sin reinicios inesperados ni caídas de voltaje | Tabla de consumo energético |
| 20 | Evaluar comportamiento de comunicación inalámbrica | Probar transmisión ESP-NOW entre nodos | La transmisión se realiza sin pérdidas significativas de eventos | Registro de transmisión inalámbrica |
| 21 | Validar interacción de control | Probar botón de reinicio y señal de reinicio a peones | El botón reinicia el sistema y los peones reciben la señal correctamente | Captura serial y evidencia visual |
| 22 | Mejorar estabilidad del firmware | Depurar el código de los subsistemas | El sistema ejecuta sus funciones sin errores críticos | Código corregido y pruebas repetidas |
| 23 | Validar funcionamiento del cronómetro central | Probar el cerebro de forma individual | La pantalla TFT muestra el estado correcto y responde a eventos | Comportamiento visible en la pantalla TFT |
| 24 | Validar funcionamiento de los peones | Probar peón de salida y peón de llegada | Los peones detectan paso y transmiten correctamente | Medición visible en monitor serial |
| 25 | Validar integración parcial del sistema | Probar el sistema conjunto en condiciones controladas | Los estados del sistema cambian correctamente de espera a carrera, recuperación y finalizado | Comportamiento visible en pantalla TFT |
| 26 | Verificar exactitud del cronometraje | Comparar tiempos medidos por el sistema en varias pruebas | Los tiempos son coherentes y repetibles entre pruebas | Registro comparativo de tiempos |
| 27 | Validar visualización remota | Probar transmisión de datos a la página web | La información mostrada en la web coincide con los datos del sistema | Correspondencia entre pantalla y página web |
| 28 | Optimizar recursos del sistema embebido | Ajustar la interfaz web para uso eficiente de memoria | El sistema opera con estabilidad manteniendo la interfaz funcional | Funcionamiento estable del ESP32 |
| 29 | Integrar físicamente todos los subsistemas | Realizar el montaje total con los diseños mecánicos definitivos | El sistema queda ensamblado y operativo físicamente | Sistema completamente ensamblado |
| 30 | Corregir desajustes detectados en integración | Aplicar correcciones finales de diseño | Los errores detectados en pruebas previas quedan corregidos | Registro de correcciones implementadas |
| 31 | Validar el sistema en entorno real | Realizar pruebas de campo | El sistema funciona fuera del entorno de laboratorio | Registro de pruebas en campo |
| 32 | Ejecutar validación final del proyecto | Realizar demostración completa en funcionamiento real | El sistema cumple los requerimientos principales en una prueba integral | Demostración funcional documentada |
| 33 | Consolidar el cierre técnico del proyecto | Organizar documentación final y evidencias | Se reúne toda la información final del proyecto en un dossier técnico | Dossier técnico consolidado |

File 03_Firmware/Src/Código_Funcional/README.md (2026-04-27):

Aquí van los códigos finales del cronometro, peones, banda y base de datos.

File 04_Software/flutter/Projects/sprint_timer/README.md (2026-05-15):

# Sprint Timer - Cronómetro Inteligente de Atletismo

Esta es una aplicación móvil desarrollada en Flutter diseñada para acompañar un sistema "Cronómetro Inteligente" con ESP32. Provee funcionalidades para registrar sesiones, ver el rendimiento de atletas, y evaluar la Eficiencia Cardiovascular (ECV).

## Requisitos
- Flutter SDK (>=3.2.0 <4.0.0)
- IDE recomendado: Android Studio o VS Code con plugins de Flutter y Dart.

## Instrucciones para Correr (Ejecución Local)

1. **Instalar dependencias**:
   ```bash
   flutter pub get
   ```

2. **(Opcional) Generar código de Drift (Base de Datos)**:
   Si modificas las entidades de base de datos en `lib/data/database/app_database.dart`, debes regenerar el código:
   ```bash
   dart run build_runner build --delete-conflicting-outputs
   ```

3. **Ejecutar en tu dispositivo o emulador**:
   ```bash
   flutter run
   ```

## Arquitectura y Estado Actual

La aplicación implementa una estructura Clean Architecture usando **BLoC/Riverpod** (actualmente BLoC) para manejo de estado, y **Drift** (SQLite) para almacenamiento local. 
Actualmente, la app se encuentra conectada a un `MockSportDataSource` que inyecta datos ficticios simulando atletas, carreras, y latidos (HR) en tiempo real, permitiendo probar la interfaz gráfica completa y el almacenamiento sin requerir hardware físico conectado.

## ¿Cómo reemplazar el MockDataSource por un RealDataSource?

Cuando el hardware (ESP32) esté listo para enviar datos (ej. mediante WebSocket, ESP-NOW vía gateway, o Bluetooth BLE), debes seguir estos pasos:

1. **Crea la nueva implementación**:
   Dirígete a `lib/data/datasources/` y crea una nueva clase (ej. `BleSportDataSource` o `WebSocketSportDataSource`) que implemente la interfaz `SportDataSource` (`lib/domain/repositories/repositories.dart`).

   ```dart
   class WebSocketSportDataSource implements SportDataSource {
     // Implementa packetStream, isConnected, connect() y disconnect()
     // traduciendo los bytes/JSON del ESP32 a DevicePacket.
   }
   ```

2. **Inyectar el nuevo DataSource en `main.dart`**:
   Cambia la instanciación en la función principal:
   ```dart
   // ANTES:
   // final dataSource = MockSportDataSource();
   
   // DESPUÉS:
   final dataSource = WebSocketSportDataSource('ws://ip-del-esp32');
   ```

3. **Listo**: 
   Como la UI (pantalla de Nueva Sesión) y los Blocs (`LiveSessionBloc`) dependen únicamente de la interfaz `SportDataSource`, **no tendrás que modificar ni una sola línea de la interfaz gráfica**. Toda la lógica de "Estado de Carrera" y almacenamiento de muestras procesará transparentemente los datos reales.

## Documentación UX/UI
Se adjuntan los documentos:
- [UX_UI_SPEC.md](UX_UI_SPEC.md): Mapa de navegación, pantallas y manejo de errores.
- [UI_KIT.md](UI_KIT.md): Paleta de colores Dark Mode, tipografía, espaciado y componentes.

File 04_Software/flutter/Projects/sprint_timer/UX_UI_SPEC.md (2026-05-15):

# Sprint Timer - Especificación UX/UI

Esta especificación detalla el mapa de navegación, las pantallas, la jerarquía visual y el manejo de estados de la aplicación "Sprint Timer".

## 1. Mapa de Navegación (User Flow)

```mermaid
graph TD
    A[Dashboard / Home] --> B(Atletas)
    A --> C(Nueva Sesión)
    A --> D(Historial)
    A --> E(Conexión)
    A --> F(Ajustes)

    B --> B1{Lista Atletas}
    B1 -->|Seleccionar| B2(Detalle Atleta)

    C --> C1{Seleccionar Atleta y Distancia}
    C1 --> C2(Sesión en Progreso)
    C2 --> C3(Resumen de Sesión)

    D --> D1{Lista de Sesiones y Filtros}
    D1 -->|Seleccionar| D2(Detalle de Sesión)

    B2 -.-> D2
```

## 2. Descripción de Pantallas

### A) Home / Dashboard
- **Objetivo**: Proveer un resumen rápido y acceso directo a las acciones principales.
- **Componentes**:
  - Encabezado: "Hola, Entrenador" + Resumen del día.
  - Quick Actions (Tarjetas de navegación): "Nueva sesión" (Destacado), "Atletas", "Historial".
  - Tarjetas pequeñas: "Estado de Conexión" y "Ajustes".
  - Lista inferior: "Últimas sesiones" (Top 3).

### B) Atletas
- **B1. Lista de Atletas**:
  - Búsqueda (Search bar) por ID o Nombre.
  - `AthleteTile`: Avatar, ID, Nombre, y "última sesión".
- **B2. Detalle de Atleta**:
  - Cabecera con Avatar, ID y Nombre.
  - Tarjetas de resumen: "Mejor tiempo 50m", "Mejor tiempo 100m".
  - Gráfica simple: Evolución del ECV o Tiempo en las últimas 5 sesiones.
  - Botón: "Ver historial completo".

### C) Nueva sesión (Registro)
- **C1. Configuración**:
  - Dropdown o chips para seleccionar Atleta (por ID).
  - Chips grandes para la Distancia (50m / 100m).
  - Estado del sistema (Cerebro: Conectado, Peón Salida: OK...).
- **C2. En Progreso**:
  - UI limpia, enfocada en la recepción de eventos.
  - Estados secuenciales: "Esperando en salida", "¡En carrera!", "Llegada", "Recuperación (HR)".
  - Botón "Simular (Mock)" si no hay sensores.
- **C3. Finalizado**:
  - Navega automáticamente al *Detalle de Sesión*.

### D) Historial
- **Filtros (FilterBar)**: Scrollable horizontal con chips (Atleta, Distancia, Rango de fechas).
- **Lista de sesiones**: `SessionTile` con información condensada (Fecha, Distancia, Tiempo, ECV).

### E) Detalle de sesión
- **Resumen principal**: Tarjetas de métricas (MetricCard) para Tiempo, Velocidad (m/s o km/h), Promedio HR (Run/Rec), y **ECV** (Eficiencia Cardiovascular).
- **Indicador de Tendencia**: Una flecha (verde arriba / roja abajo) comparada con la sesión anterior del mismo atleta en esa distancia.
- **Sección de Gráficas**: 
  - Gráfica de línea mostrando la evolución de la Frecuencia Cardíaca en el tiempo.
  - Dividida en dos regiones (Sombreado oscuro para 'Run', sombreado claro para 'Recovery').

### F) Conexión / Estado del Sistema
- **Panel de dispositivos**: 
  - "Cerebro" (Cronómetro principal)
  - "Peón de Salida"
  - "Peón de Llegada"
  - "Banda HR"
- **Estados**: Chip dinámico (Verde: Conectado, Rojo: Desconectado).
- **Métricas técnicas**: Último timestamp (Heartbeat) y calidad de señal (RSSI o %).

### G) Ajustes
- **Preferencias**: 
  - Unidades (km/h vs m/s).
  - Fórmula ECV.
  - Distancia por defecto.
- **Gestión de datos**: 
  - "Exportar datos a CSV".
  - "Borrar base de datos local".

## 3. Manejo de Estados

### 3.1. Estados Vacíos (Empty States)
- **Dashboard "Últimas sesiones"**: "Aún no hay sesiones registradas. Comienza una nueva sesión."
- **Historial**: "No se encontraron sesiones para los filtros seleccionados."
- **Atletas**: "No hay atletas en la base de datos."

### 3.2. Estados de Error
- **Pérdida de conexión en sesión**: Banner superior no intrusivo rojo "Conexión perdida con Peón de Llegada".
- **Error guardando datos**: Snackbar "Error al guardar la sesión localmente".
- **Datos insuficientes (HR)**: En detalle de sesión, si no hubo HR, mostrar la tarjeta en gris con texto "No se recibieron datos HR. ECV no disponible."

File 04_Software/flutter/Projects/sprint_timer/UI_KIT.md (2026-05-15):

# Sprint Timer - UI Kit

El diseño de "Sprint Timer" se centra en una experiencia **Dark Mode** (Modo Oscuro) por defecto, dado que es una app deportiva que puede ser utilizada en exteriores o en pistas de atletismo. El modo oscuro reduce el deslumbramiento, mejora el contraste para métricas clave, y aporta una sensación "Premium" e "Inteligente".

## 1. Paleta de Colores

Se utilizan colores de fondo profundos con acentos vibrantes para crear una jerarquía clara.

| Token de Color | Valor (Hex) | Uso Principal |
| :--- | :--- | :--- |
| **Background (Scaffold)** | `#0B0C10` | Fondo principal de las pantallas. Muy oscuro. |
| **Surface (Card)** | `#1F2833` | Fondo de tarjetas, modales y elementos elevados. |
| **Primary (Accent)** | `#66FCF1` | Botones principales, enlaces, progreso (Cian/Neón). |
| **Secondary (Accent)** | `#45A29E` | Variaciones secundarias del primary, bordes sutiles. |
| **Text Primary** | `#FFFFFF` | Textos de alto contraste (Títulos, métricas grandes). |
| **Text Secondary** | `#C5C6C7` | Textos secundarios (Subtítulos, etiquetas, leyendas). |
| **Success** | `#00E676` | Indicadores positivos (Mejora de PR, Sistema Conectado). |
| **Warning/Error** | `#FF1744` | Indicadores negativos (Desconexión, Error, Peor marca). |

## 2. Tipografía

La app emplea dos familias tipográficas (previamente configuradas en `pubspec.yaml`):

### DM Sans (UI Principal)
- Propósito: Textos descriptivos, botones, títulos.
- Estilos:
  - `HeadlineLarge`: DM Sans Bold, 32sp (Títulos de página).
  - `TitleMedium`: DM Sans SemiBold, 18sp (Títulos de tarjeta).
  - `BodyMedium`: DM Sans Regular, 14sp (Párrafos, descripciones).
  - `LabelLarge`: DM Sans Medium, 14sp (Botones).

### JetBrains Mono (Métricas y Datos)
- Propósito: Mostrar datos tabulares, cronómetros, IDs, velocidades. Al ser monoespaciada, evita saltos visuales cuando los números cambian rápidamente (ej. cronómetro en vivo).
- Estilos:
  - `DisplayLarge`: JetBrains Mono Bold, 48sp (Cronómetro en vivo).
  - `HeadlineMedium`: JetBrains Mono Bold, 24sp (Métricas en tarjetas).
  - `BodySmall`: JetBrains Mono Regular, 12sp (Fechas, IDs en listas).

## 3. Espaciado (Grid & Margins)

- Sistema basado en múltiplos de 8.
- Margen de pantalla (Screen Padding): `16px`.
- Espaciado entre componentes (Gap): `16px` o `24px` para separación de secciones.
- Borde de tarjetas (Border Radius): `16px` (Bordes redondeados, amigables pero tecnológicos).

## 4. Componentes Clave

1. **MetricCard**: 
   - Una tarjeta (Surface) que contiene un ícono o título en pequeño (Text Secondary) y un valor numérico en grande (JetBrains Mono, Text Primary).
   - Opcional: Una pequeña flecha de tendencia (Success/Error) y un % de cambio.

2. **StatusChip**:
   - Etiqueta pequeña y redondeada.
   - Variantes:
     - `Active/Connected`: Fondo verde muy translúcido (`#00E676` al 15%), texto verde.
     - `Disconnected`: Fondo rojo translúcido, texto rojo.
     - `Neutral`: Fondo gris translúcido, texto blanco/gris.

3. **SessionTile**:
   - Fila de la lista de historial.
   - Izquierda: Icono de deporte o distancia.
   - Centro: Fecha y Distancia.
   - Derecha: Tiempo principal (JetBrains Mono) y pequeño badge de ECV.

4. **FilterBar**:
   - Lista horizontal (`SingleChildScrollView` o `ListView` horizontal) con `ActionChips`.
   - Permite seleccionar rápidamente "50m", "100m", "Esta semana".

5. **ChartSection (fl_chart)**:
   - Gráfico de líneas (LineChart).
   - Fondo: Transparente.
   - Línea principal: Primary (`#66FCF1`).
   - Sombreado bajo la línea: Gradiente del Primary hacia transparente (`#66FCF1` con `alpha 0.3` a `0.0`).
   - Grid lines: Ocultas o muy tenues (`alpha 0.1`) para no saturar.

## 5. Micro-Interacciones (Animaciones)
- Las transiciones de pantalla utilizan *Fade* o *Slide* muy rápido (200ms) para dar sensación de velocidad, acorde a la temática de "sprints".
- Al presionar un botón o tarjeta, debe haber un efecto sutil de escalado (`ScaleTransition` al 0.98).

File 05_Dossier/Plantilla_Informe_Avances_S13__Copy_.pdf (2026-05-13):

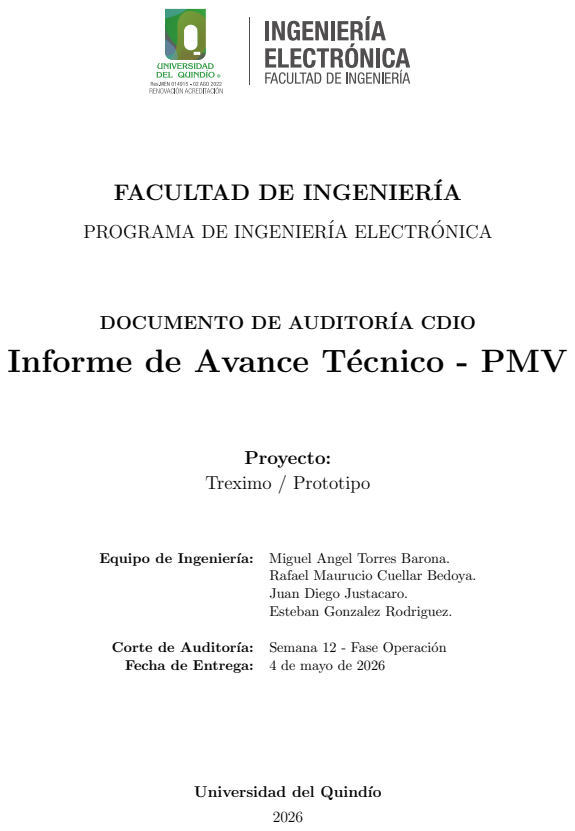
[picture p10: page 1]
Proyecto: Treximo / Prototipo; Equipo de Ingeniería:; Miguel Angel Torres Barona.; Corte de Auditoría:; Semana 12 - Fase Operación; Fecha de Entrega:; 4 de mayo de 2026

FACULTAD DE INGENIERÍA

PROGRAMA DE INGENIERÍA ELECTRONICA ´

DOCUMENTO DE AUDITORÍA CDIO

Informe de Avance Técnico - PMV

Rafael Maurucio Cuellar Bedoya.
Juan Diego Justacaro.
Esteban Gonzalez Rodriguez.

Universidad del Quindío

## Índice

1. Resumen Ejecutivo | 2
2. Estado de Cumplimiento ON-Ramp | 2
3. Resultados de Verificación y Validación (V&V) | 2
4. Desempeño Operativo (MAHD + Kanban) | 3
5. Auditoría Financiera (CVU) | 4
6. Próximos Pasos (Roadmap S12 a S14) | 4
7. Anexos y Evidencia Técnica | 5

## 1. Resumen Ejecutivo

El proyecto se encuentra en estado AMARILLO. Durante el último ciclo IPAC (IPAC 6/9) se logró la integración funcional de sensores, la comunicación entre nodos mediante ESP-NOW y la validación operativa del cronómetro central. El sistema evolucionó desde una arquitectura con distancia fija hacia una arquitectura distribuida compuesta por cronómetro, peones y banda fisiológica, incorporando medición de distancia mediante UWB. Actualmente, el hardware se encuentra parcialmente validado y operativo, con fallos identificados en la medición de distancia real entre peones. El principal riesgo técnico radica en la integración completa del sistema UWB, la estabilidad del firmware final y la validación en condiciones reales de campo. El siguiente hito consiste en la validación individual de módulos críticos y el montaje parcial del sistema completo para pruebas de integración.

## 2. Estado de Cumplimiento ON-Ramp

Tabla 1: Trazabilidad de Requisitos de la Matriz ON-Ramp vs. PMV Actual

ID | Requisito Original (Promesa) | Estado | Observaciones / Desviaciones
REQ-01 | Medir tiempo de carrera | Parcial | Máquina de estados implementa- da: espera, carrera, recuperación y finalizado.
REQ-02 | Detectar salida y llegada au- tomáticamente | Logrado | Implementado con ESP32 y HC- SR04. Comunicación ESP-NOW validada.
REQ-03 | Medir velocidad del atleta | En rediseño | Error detectado por uso de distan- cia fija. Se incorpora UWB.
REQ-04 | Medir frecuencia cardíaca | Logrado | Implementación con MAX30102 / PulseSensor.
REQ-05 | Mostrar datos al entrenador | Parcial | Visualización en OLED/TFT y dashboard básico.
REQ-06 | Registrar histórico | Parcial | Interfaz Flutter con datos simula- dos.
REQ-07 | Sistema portátil | Parcial | Uso de baterías LiPo y sistema de carga TP4056.

Como se detalla en la Tabla 1, el equipo ha priorizado los requisitos críticos del sistema para la consolidación del Producto Mínimo Viable (PMV).

## 3. Resultados de Verificación y Validación (V&V)

El proceso de Verificación y Validación se ha ejecutado conforme al protocolo establecido. La Tabla 3 consolida las métricas de éxito y los puntos de fallo detectados durante las pruebas de integración en laboratorio.

Tabla 2: Consolidado de Ejecución de Pruebas Técnicas

ID Prueba | Parámetro Evaluado | Resultado | Causa Raíz (Si aplica) /
Dato Registrado
PRB-01 | Comunicación ESP-NOW | Exito | Recepción correcta de men- ´
sajes SALIDA/LLEGADA en
monitor serial.
PRB-02 | Sensor HC-SR04 | Parcial | Detección funcional, requiere
calibración de umbral.
PRB-03 | Cronómetro central | Parcial | Transición de estados funcio-
nal, requiere pruebas en campo.
PRB-04 | Botón de reinicio | Exito | Reinicio local y señal a peones ´
validado.
PRB-05 | Sensor fisiológico | Fallo parcial | Integración incompleta, señal
inestable.
PRB-06 | Medición UWB | Fallo | Problemas en integración ini-
cial, requiere validación contra medición física.
PRB-07 | Interfaz web ESP32 | Exito | Visualización básica funcional. ´
PRB-08 | Interfaz Flutter | Parcial | Mock funcional, no conectado
a hardware real.

Tabla 3: Consolidado de Ejecución de Pruebas Técnicas

ID Prueba | Parámetro Evaluado | Resultado | Causa Raíz (Si aplica) / Da-
to Registrado
PRB-01 | Tolerancia a ruido eléctrico. | Exito | Ruido filtrado con condensador ´
cerámico de 100nF.
PRB-02 | Límite | de | temperatura | del
MOSFET.

Fallo Superó los 85°C. Requiere disipador pasivo urgente.
PRB-03 | Reconexión automática de red. | Exito | Tiempo de reconexión promedio ´
medido: 4.5 segundos.

## 4. Desempeño Operativo (MAHD + Kanban)

### 4.1. Gestión de Flujo y Cuellos de Botella

El principal cuello de botella identificado corresponde al módulo de medición de distancia mediante UWB, el cual ha requerido múltiples iteraciones de integración sin alcanzar validación completa. Adicionalmente, la simultaneidad en desarrollo de hardware, firmware e interfaz ha generado sobrecarga operativa. Se recomienda limitar el trabajo en progreso (WIP) a tres tareas activas por integrante y priorizar pruebas unitarias antes de la integración total.

### 4.2. Estado del Repositorio (GitHub)

El repositorio se encuentra estructurado en cuatro módulos: Gestión, Hardware, Firmware y Dossier. Se han definido issues para cada subsistema (cronómetro, peones, banda fisiológica e interfaz), permitiendo trazabilidad de tareas. La estrategia de ramas contempla desarrollo aislado para nuevas funcionalidades antes de integración en la rama principal.

## 5. Auditoría Financiera (CVU)

Tabla 4: Auditoría de Costos de Hardware (Presupuestado vs. Real)

Subsistema / Módulo | Costo Presupuestado | Costo Real | Desviación
Cronómetro | $200.000 | $230.000 | +15 %
Peones (x2) | $300.000 | $320.000 | +6.6 %
Banda fisiológica | $150.000 | $164.560 | +9.7 %
Costo Total (CVU) | $650.000 | $714.560 | +9.9 %

### 5.1. Justificación de Desviaciones Financieras (si aplica)

Las desviaciones se deben principalmente al ajuste del diseño para incorporar el módulo UWB y a variaciones en el costo de componentes electrónicos. No se reportan pérdidas por daño de componentes, pero sí ajustes derivados de rediseño técnico.

### 5.2. Justificación de Desviaciones Financieras (si aplica)

Las desviaciones se deben principalmente al ajuste del diseño para incorporar el módulo UWB y a variaciones en el costo de componentes electrónicos. No se reportan pérdidas por daño de componentes, pero sí ajustes derivados de rediseño técnico.

## 6. Próximos Pasos (Roadmap S12 a S14)

1. Validar completamente el módulo UWB mediante comparación con medición física.
2. Optimizar consumo energético del sistema para operación portátil.
3. Integrar completamente la banda fisiológica con el cronómetro.
4. Finalizar conexión de la interfaz Flutter con datos reales.
5. Ejecutar prueba de campo en condiciones reales de carrera.
6. Consolidar documentación técnica final (dossier CDIO).

## 7. Anexos y Evidencia Técnica

### 7.1. Evidencia de Gestión (Kanban)

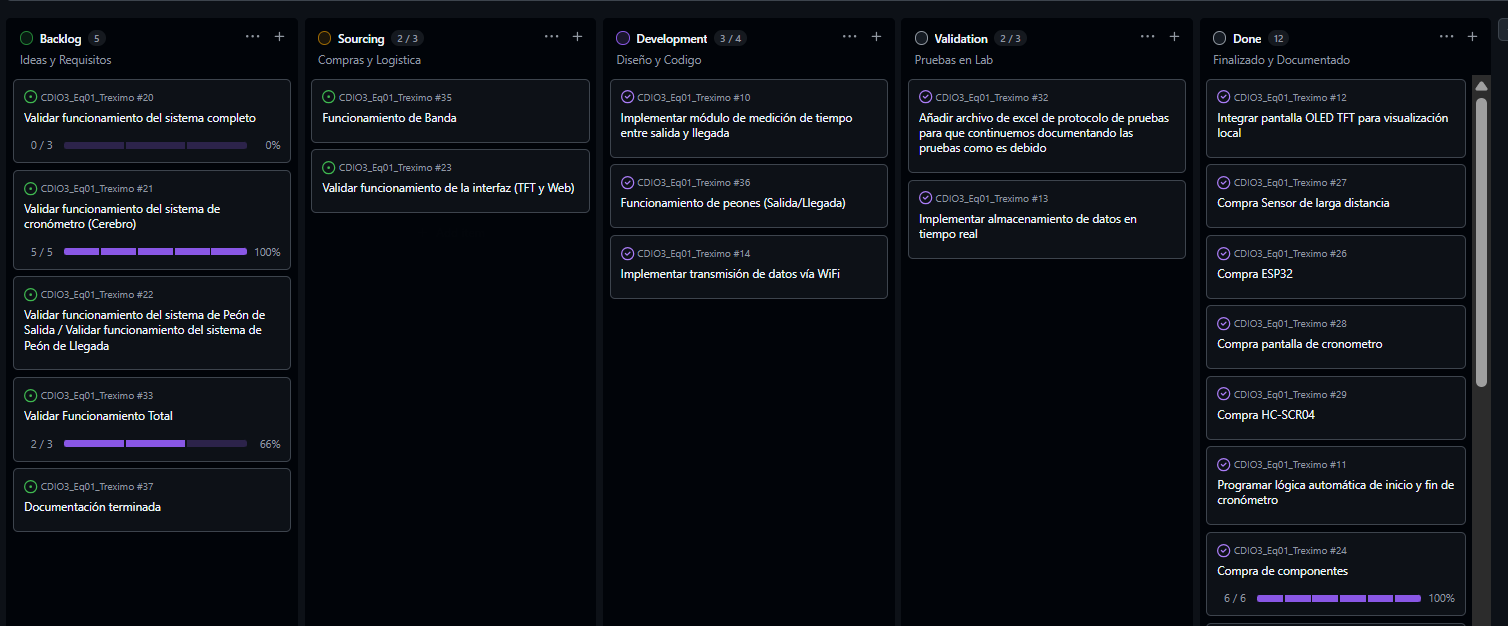
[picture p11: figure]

Figura 1: Estado actual del tablero Kanban del proyecto TREXIMO, donde se evidencia la distribución de tareas en backlog, desarrollo, validación y finalizadas.

El tablero Kanban permite visualizar el flujo de trabajo del equipo, identificando el estado de cada tarea y los cuellos de botella presentes en el desarrollo del sistema. Se observa una concentración de tareas finalizadas y un número reducido en validación, lo que evidencia avance significativo pero también la necesidad de fortalecer la etapa de pruebas.

### 7.2. Notas Técnicas

La evidencia presentada corresponde al estado real del proyecto durante el corte de auditoría.

Las pruebas técnicas del sistema se encuentran documentadas en la sección de Verificación y Validación.

La integración completa del sistema aún se encuentra en proceso de validación.

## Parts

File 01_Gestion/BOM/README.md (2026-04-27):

# Bill Of Materials (BOM)
Este documento detalla todos los componentes electrónicos, electromecánicos y materiales de manufactura necesarios para un sistema básico para construir un sistema funcional.

# Cronometro
| Ítem | Componente | Cant. | Referencia / Especificación | Función | Est. Costo (COP) |
| :--- | :--- | :---: | :--- | :--- | :---: |
| 1 | **Microcontrolador** | 1 | **ESP32 DevKit V1 / ESP32-WROOM-32 DevKit** | Procesamiento principal del cronómetro, control de estados y comunicaciones | $ 31.178 |
| 2 | **Pantalla TFT** | 1 | **TFT SPI ST7735 1.77” / 160x128** | Visualización local de tiempo, estado y frecuencia cardíaca | $ 34.600 |
| 3 | **Batería recargable** | 1 | **LiPo / Li-ion 3.7 V 2200 mAh** | Alimentación portátil del cronómetro | $ 20.000 |
| 4 | **Módulo de carga** | 1 | **TP4056 con protección** | Carga segura de la batería del cronómetro | $ 5.500 |
| 5 | **Reloj de Tiempo Real**| 1 | **Caja impresa en PLA** | Protección mecánica e integración física del cronómetro | $ 20.000 |
| 6 | **Indicador visual** | 1 | **LED + resistencia** | Confirmación visual de estados y eventos | $ 1.000 |
| 7 | **Carcasa** | 1 | **Caja impresa en PLA** | Protección mecánica e integración física del cronómetro | $ 20.000 |
# Peon
| Ítem | Componente | Cant. | Referencia / Especificación | Función | Est. Costo (COP) |
| :--- | :--- | :---: | :--- | :--- | :---: |
| 12 | **Microcontrolador** | 1 | **ESP32 DevKit V1 / ESP32-WROOM-32 DevKit** | Control del peón y transmisión de eventos | $ 31.178 |
| 13 | **Sensor de presencia** | 1 | **HC-SR04** | Detección del paso del atleta | $ 6.900 |
| 14 | **Módulo UWB** | 1 | **BU01** | Medición de distancia entre peones | $ 84.410 |
| 15 | **Batería recargable**  | 1 | **LiPo / Li-ion 3.7 V 2200 mAh** | Alimentación portátil del peón | $ 20.000 |
| 16 | **Módulo de carga** | 1 | **TP4056 con protección** | Carga segura de la batería del peón | $ 5.500 |
| 17 | **Carcasa** | 1 | **Caja impresa en PLA** | Protección e integración física del peón  | $ 20.000 |
| 18 | **Indicador visual** | 1 | **LED + resistencia** | Confirmación visual de detección y estado | $ 1.000 |

# Banda
| Ítem | Componente | Cant. | Referencia / Especificación | Función | Est. Costo (COP) |
| :--- | :--- | :---: | :--- | :--- | :---: |
| 7 | **Microcontrolador** | 1 | **ESP32 DevKit V1 / ESP32-WROOM-32 DevKit** | Adquisición y transmisión de datos fisiológicos | $ 31.178 |
| 8 | **Sensor de frecuencia cardíaca** | 1 | **PulseSensor genérico** | Medición de la frecuencia cardíaca del atleta | $ 9.758 |
| 9 | **Batería recargable** | 1 | **LiPo / Li-ion 3.7 V 2200 mAh** | Alimentación autónoma de la banda | $ 20.000 |
| 10 | **Módulo de carga** | 1 | **TP4056 con protección** | Carga segura de la batería de la banda | $ 5.500 |
| 11 | **Carcasa / soporte** | 1 | **Caja impresa en PLA** | Integración mecánica del módulo fisiológico | $ 20.000 |

# Sistema completo
| Categoría | Subtotal Estimado |
| :--- | :--- |
| Cronómetro | $ 112.278 |
| Peón | $ 168.988 |
| Peón | $ 168.988 |
| Banda | $ 86.436 |
| **TOTAL SISTEMA COMPLETO (Cronómetro + Banda + 2 Peones)** | **$ 536.690 COP** |

*(Precios estimados en mercado local colombiano - MercadoLibre / Electrónicas locales a Feb 2026)*

---

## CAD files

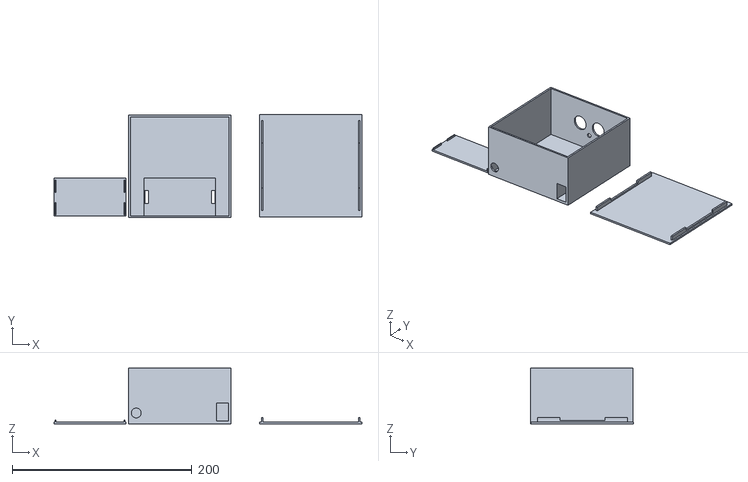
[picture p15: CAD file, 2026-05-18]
02_Hardware/Mechanical/Peones_V2.stl
342.8 x 115.0 x 62.2

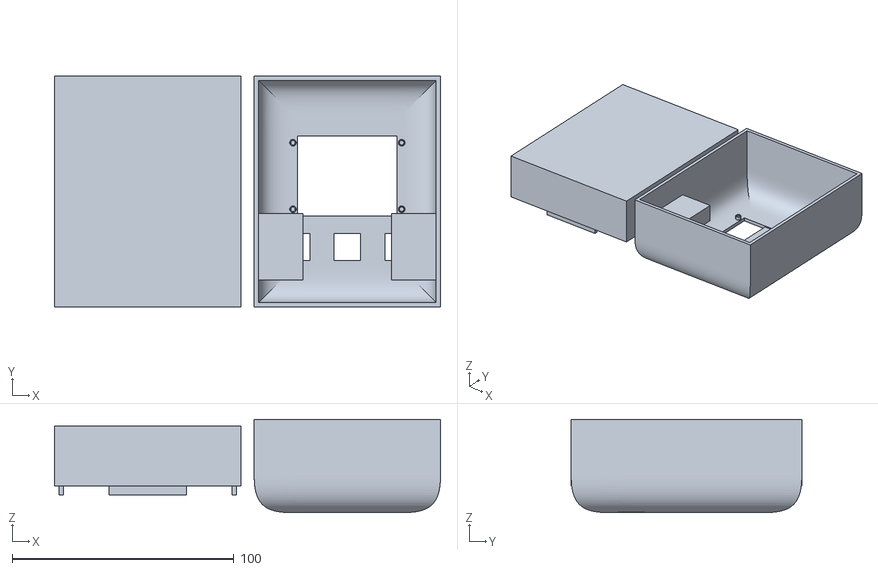
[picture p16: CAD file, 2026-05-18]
02_Hardware/Mechanical/Cronometro_V2.stl
174.0 x 104.0 x 42.0

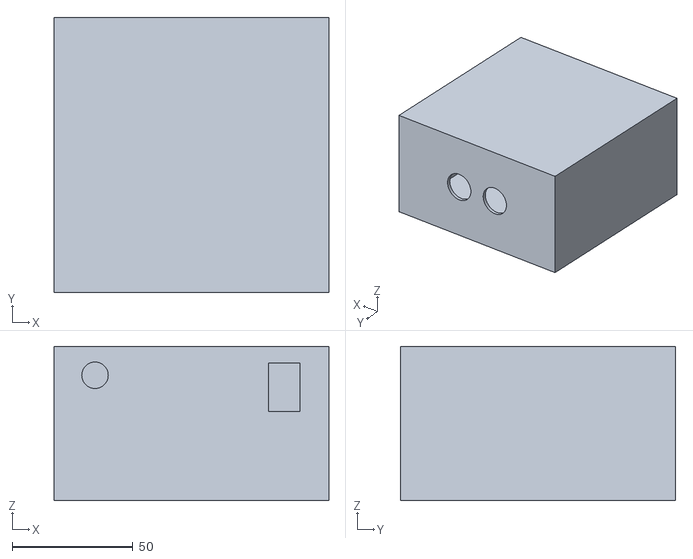
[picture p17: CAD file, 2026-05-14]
02_Hardware/Mechanical/PeonesMiguelTorresSTL.stl
114.0 x 114.0 x 64.0

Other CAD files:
02_Hardware/Mechanical/CronometroV2.stl

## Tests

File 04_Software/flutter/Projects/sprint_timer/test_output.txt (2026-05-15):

00:00 +0: loading C:/Users/Migue/Downloads/flutter/Projects/sprint_timer/test/widget_test.dart
00:00 +0: App builds without errors smoke test
ÔòÉÔòÉÔòí EXCEPTION CAUGHT BY WIDGETS LIBRARY Ôò×ÔòÉÔòÉÔòÉÔòÉÔòÉÔòÉÔòÉÔòÉÔòÉÔòÉÔòÉÔòÉÔòÉÔòÉÔòÉÔòÉÔòÉÔòÉÔòÉÔòÉÔòÉÔòÉÔòÉÔòÉÔòÉÔòÉÔòÉÔòÉÔòÉÔòÉÔòÉÔòÉÔòÉÔòÉÔòÉÔòÉÔòÉÔòÉÔòÉÔòÉÔòÉÔòÉÔòÉÔòÉÔòÉÔòÉÔòÉÔòÉÔòÉÔòÉÔòÉÔòÉÔòÉÔòÉÔòÉÔòÉÔòÉÔòÉÔòÉ
The following LocaleDataException was thrown building HomeScreen(dirty):
Locale data has not been initialized, call initializeDateFormatting(<locale>).

The relevant error-causing widget was:
  HomeScreen
  HomeScreen:file:///C:/Users/Migue/Downloads/flutter/Projects/sprint_timer/lib/main.dart:42:44

When the exception was thrown, this was the stack:
#0      UninitializedLocaleData._throwException (package:intl/src/intl_helpers.dart:80:5)
#1      UninitializedLocaleData.containsKey (package:intl/src/intl_helpers.dart:74:7)
#2      DateFormat.localeExists (package:intl/src/intl/date_format.dart:902:28)
#3      verifiedLocale (package:intl/src/intl_helpers.dart:185:19)
#4      new DateFormat (package:intl/src/intl/date_format.dart:267:27)
#5      HomeScreen.build (package:sprint_timer/presentation/screens/screens_a.dart:34:25)
#6      StatelessElement.build (package:flutter/src/widgets/framework.dart:5889:49)
#7      ComponentElement.performRebuild (package:flutter/src/widgets/framework.dart:5817:15)
#8      Element.rebuild (package:flutter/src/widgets/framework.dart:5529:7)
#9      ComponentElement._firstBuild (package:flutter/src/widgets/framework.dart:5799:5)
#10     ComponentElement.mount (package:flutter/src/widgets/framework.dart:5793:5)
...     Normal element mounting (266 frames)
#276    Element.inflateWidget (package:flutter/src/widgets/framework.dart:4587:20)
#277    MultiChildRenderObjectElement.inflateWidget (package:flutter/src/widgets/framework.dart:7264:36)
#278    MultiChildRenderObjectElement.mount (package:flutter/src/widgets/framework.dart:7279:32)
...     Normal element mounting (491 frames)
#769    _InheritedProviderScopeElement.mount (package:provider/src/inherited_provider.dart:424:11)
...     Normal element mounting (7 frames)
#776    SingleChildWidgetElementMixin.mount (package:nested/nested.dart:222:11)
...     Normal element mounting (7 frames)
#783    SingleChildWidgetElementMixin.mount (package:nested/nested.dart:222:11)
...     Normal element mounting (7 frames)
#790    _NestedHookElement.mount (package:nested/nested.dart:187:11)
...     Normal element mounting (7 frames)
#797    _InheritedProviderScopeElement.mount (package:provider/src/inherited_provider.dart:424:11)
...     Normal element mounting (7 frames)
#804    SingleChildWidgetElementMixin.mount (package:nested/nested.dart:222:11)
...     Normal element mounting (7 frames)
#811    SingleChildWidgetElementMixin.mount (package:nested/nested.dart:222:11)
...     Normal element mounting (7 frames)
#818    _NestedHookElement.mount (package:nested/nested.dart:187:11)
...     Normal element mounting (7 frames)
#825    SingleChildWidgetElementMixin.mount (package:nested/nested.dart:222:11)
...     Normal element mounting (7 frames)
#832    Element.inflateWidget (package:flutter/src/widgets/framework.dart:4587:20)
#833    Element.updateChild (package:flutter/src/widgets/framework.dart:4053:20)
#834    ComponentElement.performRebuild (package:flutter/src/widgets/framework.dart:5841:16)
#835    Element.rebuild (package:flutter/src/widgets/framework.dart:5529:7)
#836    ProxyElement.update (package:flutter/src/widgets/framework.dart:6149:5)
#837    _InheritedNotifierElement.update (package:flutter/src/widgets/inherited_notifier.dart:108:11)
#838    Element.updateChild (package:flutter/src/widgets/framework.dart:4037:15)
#839    ComponentElement.performRebuild (package:flutter/src/widgets/framework.dart:5841:16)
#840    StatefulElement.performRebuild (package:flutter/src/widgets/framework.dart:5982:11)
#841    Element.rebuild (package:flutter/src/widgets/framework.dart:5529:7)
#842    StatefulElement.update (package:flutter/src/widgets/framework.dart:6007:5)
#843    Element.updateChild (package:flutter/src/widgets/framework.dart:4037:15)
#844    ComponentElement.performRebuild (package:flutter/src/widgets/framework.dart:5841:16)
#845    Element.rebuild (package:flutter/src/widgets/framework.dart:5529:7)
#846    ProxyElement.update (package:flutter/src/widgets/framework.dart:6149:5)
#847    _InheritedNotifierElement.update (package:flutter/src/widgets/inherited_notifier.dart:108:11)
#848    Element.updateChild (package:flutter/src/widgets/framework.dart:4037:15)
#849    ComponentElement.performRebuild (package:flutter/src/widgets/framework.dart:5841:16)
#850    StatefulElement.performRebuild (package:flutter/src/widgets/framework.dart:5982:11)
#851    Element.rebuild (package:flutter/src/widgets/framework.dart:5529:7)
#852    StatefulElement.update (package:flutter/src/widgets/framework.dart:6007:5)
#853    Element.updateChild (package:flutter/src/widgets/framework.dart:4037:15)
#854    ComponentElement.performRebuild (package:flutter/src/widgets/framework.dart:5841:16)
#855    StatefulElement.performRebuild (package:flutter/src/widgets/framework.dart:5982:11)
#856    Element.rebuild (package:flutter/src/widgets/framework.dart:5529:7)
#857    StatefulElement.update (package:flutter/src/widgets/framework.dart:6007:5)
#858    Element.updateChild (package:flutter/src/widgets/framework.dart:4037:15)
#859    ComponentElement.performRebuild (package:flutter/src/widgets/framework.dart:5841:16)
#860    Element.rebuild (package:flutter/src/widgets/framework.dart:5529:7)
#861    ProxyElement.update (package:flutter/src/widgets/framework.dart:6149:5)
#862    Element.updateChild (package:flutter/src/widgets/framework.dart:4037:15)
#863    ComponentElement.performRebuild (package:flutter/src/widgets/framework.dart:5841:16)
#864    StatefulElement.performRebuild (package:flutter/src/widgets/framework.dart:5982:11)
#865    Element.rebuild (package:flutter/src/widgets/framework.dart:5529:7)
#866    StatefulElement.update (package:flutter/src/widgets/framework.dart:6007:5)
#867    Element.updateChild (package:flutter/src/widgets/framework.dart:4037:15)
#868    ComponentElement.performRebuild (package:flutter/src/widgets/framework.dart:5841:16)
#869    Element.rebuild (package:flutter/src/widgets/framework.dart:5529:7)
#870    ProxyElement.update (package:flutter/src/widgets/framework.dart:6149:5)
#871    Element.updateChild (package:flutter/src/widgets/framework.dart:4037:15)
#872    ComponentElement.performRebuild (package:flutter/src/widgets/framework.dart:5841:16)
#873    Element.rebuild (package:flutter/src/widgets/framework.dart:5529:7)
#874    ProxyElement.update (package:flutter/src/widgets/framework.dart:6149:5)
#875    Element.updateChild (package:flutter/src/widgets/framework.dart:4037:15)
#876    _RawViewElement._updateChild (package:flutter/src/widgets/view.dart:481:16)
#877    _RawViewElement.update (package:flutter/src/widgets/view.dart:568:5)
#878    Element.updateChild (package:flutter/src/widgets/framework.dart:4037:15)
#879    ComponentElement.performRebuild (package:flutter/src/widgets/framework.dart:5841:16)
#880    Element.rebuild (package:flutter/src/widgets/framework.dart:5529:7)
#881    StatelessElement.update (package:flutter/src/widgets/framework.dart:5895:5)
#882    Element.updateChild (package:flutter/src/widgets/framework.dart:4037:15)
#883    ComponentElement.performRebuild (package:flutter/src/widgets/framework.dart:5841:16)
#884    StatefulElement.performRebuild (package:flutter/src/widgets/framework.dart:5982:11)
#885    Element.rebuild (package:flutter/src/widgets/framework.dart:5529:7)
#886    StatefulElement.update (package:flutter/src/widgets/framework.dart:6007:5)
#887    Element.updateChild (package:flutter/src/widgets/framework.dart:4037:15)
#888    RootElement._rebuild (package:flutter/src/widgets/binding.dart:1822:16)
#889    RootElement.update (package:flutter/src/widgets/binding.dart:1800:5)
#890    RootElement.performRebuild (package:flutter/src/widgets/binding.dart:1814:7)
#891    Element.rebuild (package:flutter/src/widgets/framework.dart:5529:7)
#892    BuildScope._tryRebuild (package:flutter/src/widgets/framework.dart:2750:15)
#893    BuildScope._flushDirtyElements (package:flutter/src/widgets/framework.dart:2807:11)
#894    BuildOwner.buildScope (package:flutter/src/widgets/framework.dart:3111:18)
#895    AutomatedTestWidgetsFlutterBinding.drawFrame (package:flutter_test/src/binding.dart:2131:19)
#896    RendererBinding._handlePersistentFrameCallback (package:flutter/src/rendering/binding.dart:495:5)
#897    SchedulerBinding._invokeFrameCallback (package:flutter/src/scheduler/binding.dart:1430:15)
#898    SchedulerBinding.handleDrawFrame (package:flutter/src/scheduler/binding.dart:1345:9)
#899    AutomatedTestWidgetsFlutterBinding.pump.<anonymous closure> (package:flutter_test/src/binding.dart:1960:9)
#902    TestAsyncUtils.guard (package:flutter_test/src/test_async_utils.dart:74:41)
#903    AutomatedTestWidgetsFlutterBinding.pump (package:flutter_test/src/binding.dart:1949:27)
#904    WidgetTester.pumpWidget.<anonymous closure> (package:flutter_test/src/widget_tester.dart:598:22)
#907    TestAsyncUtils.guard (package:flutter_test/src/test_async_utils.dart:74:41)
#908    WidgetTester.pumpWidget (package:flutter_test/src/widget_tester.dart:595:27)
#909    main.<anonymous closure> (file:///C:/Users/Migue/Downloads/flutter/Projects/sprint_timer/test/widget_test.dart:12:18)
#910    testWidgets.<anonymous closure>.<anonymous closure> (package:flutter_test/src/widget_tester.dart:192:29)
<asynchronous suspension>
#911    TestWidgetsFlutterBinding._runTestBody (package:flutter_test/src/binding.dart:1682:5)
<asynchronous suspension>
<asynchronous suspension>
(elided 5 frames from dart:async and package:stack_trace)

ÔòÉÔòÉÔòÉÔòÉÔòÉÔòÉÔòÉÔòÉÔòÉÔòÉÔòÉÔòÉÔòÉÔòÉÔòÉÔòÉÔòÉÔòÉÔòÉÔòÉÔòÉÔòÉÔòÉÔòÉÔòÉÔòÉÔòÉÔòÉÔòÉÔòÉÔòÉÔòÉÔòÉÔòÉÔòÉÔòÉÔòÉÔòÉÔòÉÔòÉÔòÉÔòÉÔòÉÔòÉÔòÉÔòÉÔòÉÔòÉÔòÉÔòÉÔòÉÔòÉÔòÉÔòÉÔòÉÔòÉÔòÉÔòÉÔòÉÔòÉÔòÉÔòÉÔòÉÔòÉÔòÉÔòÉÔòÉÔòÉÔòÉÔòÉÔòÉÔòÉÔòÉÔòÉÔòÉÔòÉÔòÉÔòÉÔòÉÔòÉÔòÉÔòÉÔòÉÔòÉÔòÉÔòÉÔòÉÔòÉÔòÉÔòÉÔòÉÔòÉÔòÉÔòÉÔòÉÔòÉÔòÉÔòÉÔòÉÔòÉ
00:00 +0 -1: App builds without errors smoke test [E]
  Test failed. See exception logs above.
  The test description was: App builds without errors smoke test
  
00:00 +0 -1: Some tests failed.

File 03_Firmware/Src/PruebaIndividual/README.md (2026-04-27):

Esta carpeta será utilizada para subir los códigos de prueba individual de cada componente del sistema.

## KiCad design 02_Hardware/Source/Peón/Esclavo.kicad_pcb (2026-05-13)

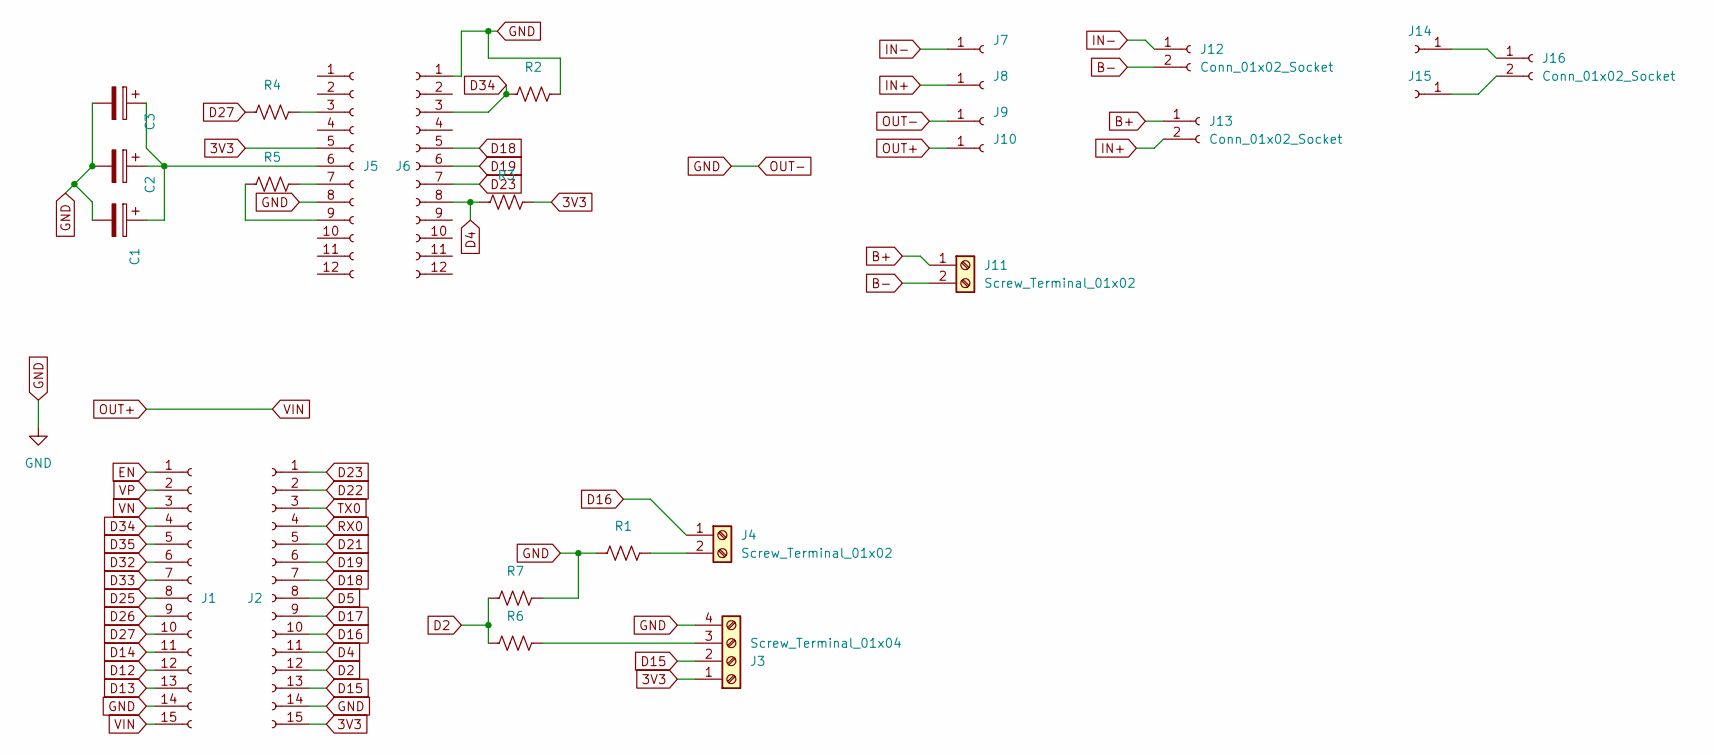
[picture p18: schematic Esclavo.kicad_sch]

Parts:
C1, C2, C3: C_Polarized; CP_Radial_D5.0mm_P2.50mm
J1, J2: Conn_01x15_Socket; PinSocket_1x15_P2.54mm_Vertical
J3: Screw_Terminal_01x04; TerminalBlock_Phoenix_MKDS-1,5-4-5.08_1x04_P5.08mm_Horizont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
J4, J11: Screw_Terminal_01x02; TerminalBlock_Phoenix_MKDS-1,5-2-5.08_1x02_P5.08mm_Horizont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
J5, J6: Conn_01x12_Socket; PinSocket_1x12_P2.54mm_Vertical
J7, J8, J9, J10, J14, J15: Conn_01x01_Socket; PinHeader_1x01_P2.54mm_Vertical
J12, J13, J16: Conn_01x02_Socket; PinSocket_1x02_P2.54mm_Vertical
R1, R2, R3, R4, R5, R6, R7: R_US; R_Axial_DIN0207_L6.3mm_D2.5mm_P10.16mm_Horizontal

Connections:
3V3: J2.15, J3.1, J5.5, R3.1
B+: J11.1, J13.1
B-: J11.2, J12.2
D2: J2.12, R6.2, R7.2
D4: J2.11, J6.8, R3.2
D5: J2.8
D12: J1.12
D13: J1.13
D14: J1.11
D15: J2.13, J3.2
D16: J2.10, J4.1
D17: J2.9
D18: J2.7, J6.5
D19: J2.6, J6.6
D21: J2.5
D22: J2.2
D23: J2.1, J6.7
D25: J1.8
D26: J1.9
D27: J1.10, R4.2
D32: J1.6
D33: J1.7
D34: J1.4, J6.3, R2.2
D35: J1.5
EN: J1.1
GND: C1.2, C2.2, C3.2, J1.14, J2.14, J3.4, J5.8, J6.1, J9.1 (Pin_1_1), R1.2, R2.1, R7.1
IN+: J8.1 (Pin_1_1), J13.2
IN-: J7.1 (Pin_1_1), J12.1
unnamed: J3.3, R6.1
unnamed: J4.2, R1.1
unnamed: J5.3, R4.1
unnamed: C1.1, C2.1, C3.1, J5.6
unnamed: J5.7, R5.1
unnamed: J5.9, R5.2
unnamed: J14.1 (Pin_1_1), J16.1
unnamed: J15.1 (Pin_1_1), J16.2
OUT+: J1.15, J10.1 (Pin_1_1)
RX0: J2.4
TX0: J2.3
VN: J1.3
VP: J1.2

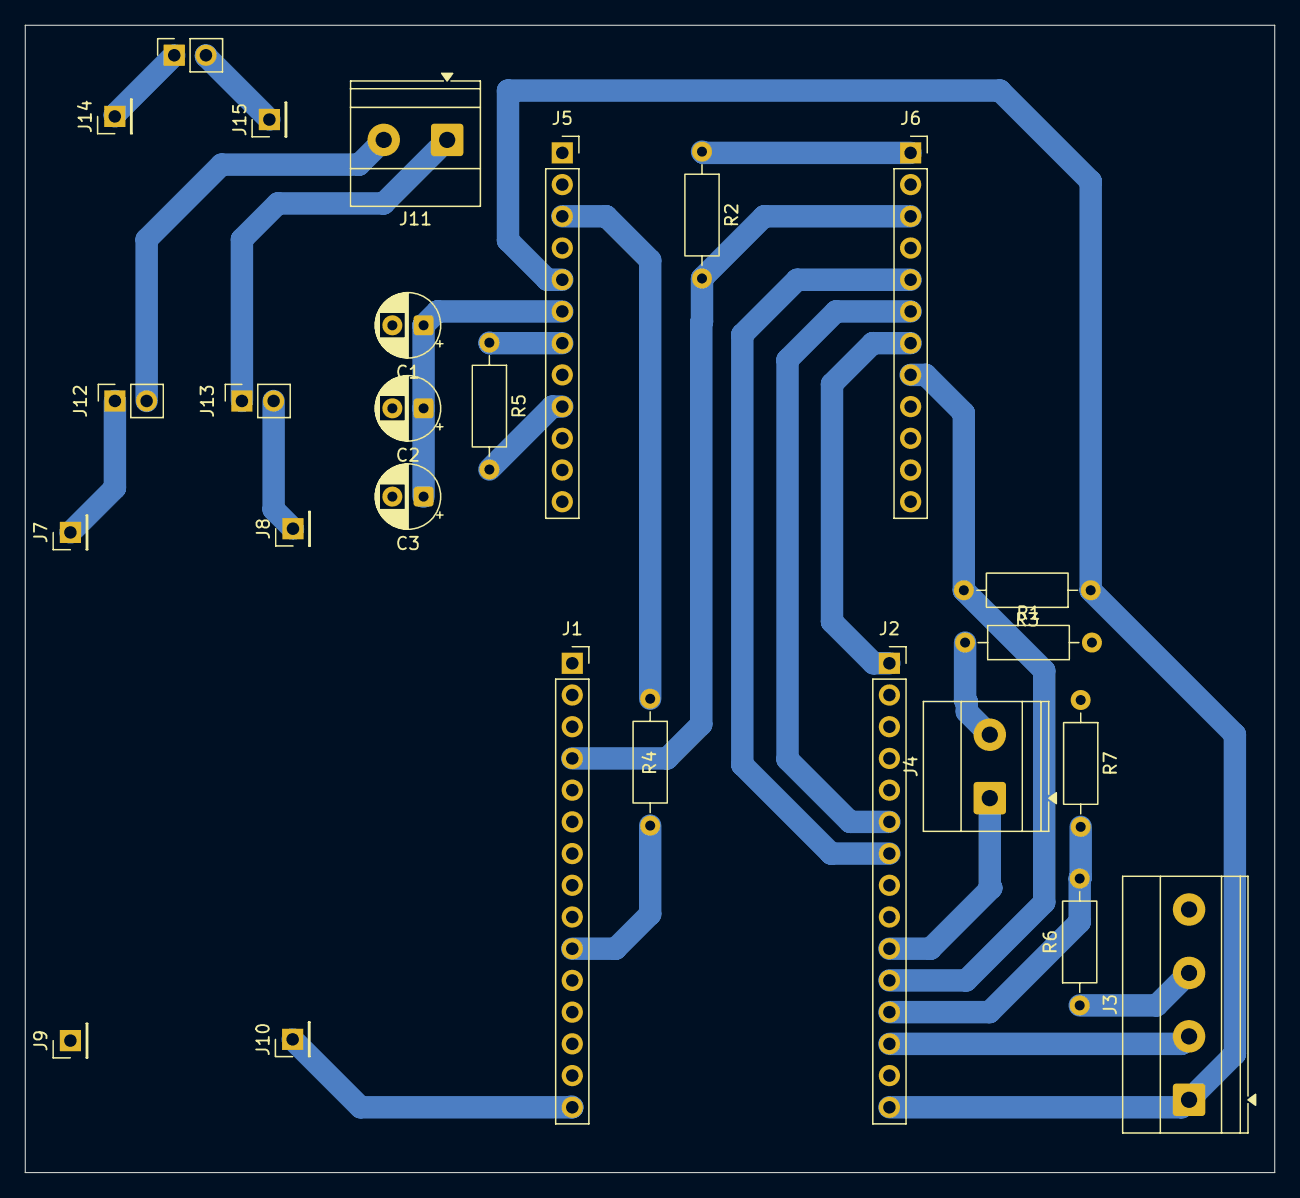
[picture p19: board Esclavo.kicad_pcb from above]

Board: 2 copper layers, 100.1 x 91.9 mm, 26 parts (0 on the bottom side), 24 nets.

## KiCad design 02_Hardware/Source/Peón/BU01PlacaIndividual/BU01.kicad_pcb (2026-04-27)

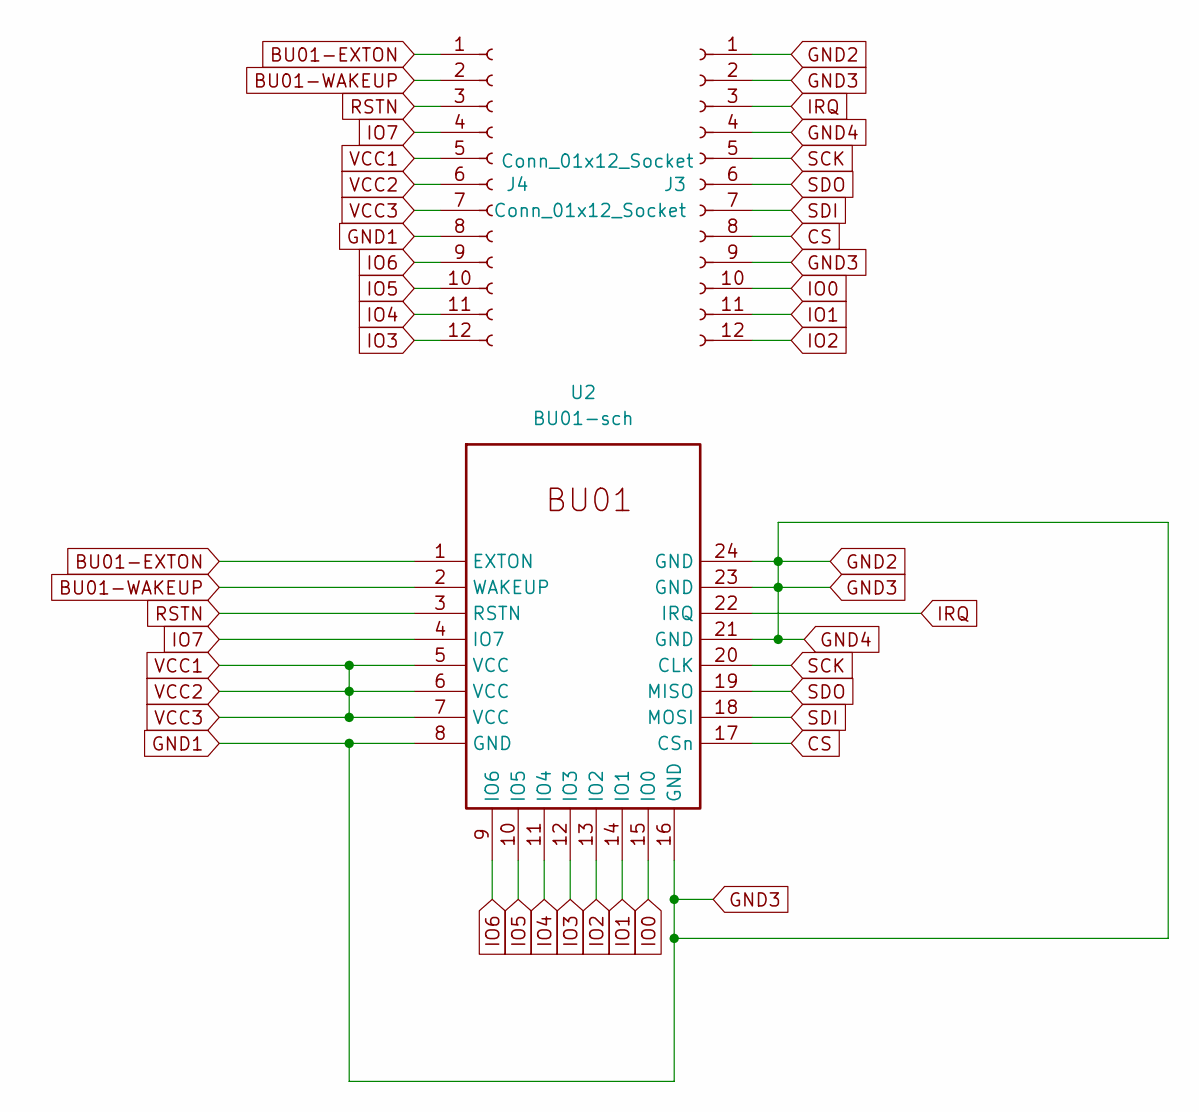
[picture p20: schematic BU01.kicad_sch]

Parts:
J3, J4: Conn_01x12_Socket; PinSocket_1x12_P2.54mm_Vertical
U2: BU01-sch; BU01

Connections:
BU01-EXTON: J4.1, U2.1 (EXTON)
BU01-WAKEUP: J4.2, U2.2 (WAKEUP)
CS: J3.8, U2.17 (CSn)
GND1: J3.1, J3.2, J3.4, J3.9, J4.8, U2.8 (GND), U2.16 (GND), U2.21 (GND), U2.23 (GND), U2.24 (GND)
IO0: J3.10, U2.15 (IO0)
IO1: J3.11, U2.14 (IO1)
IO2: J3.12, U2.13 (IO2)
IO3: J4.12, U2.12 (IO3)
IO4: J4.11, U2.11 (IO4)
IO5: J4.10, U2.10 (IO5)
IO6: J4.9, U2.9 (IO6)
IO7: J4.4, U2.4 (IO7)
IRQ: J3.3, U2.22 (IRQ)
RSTN: J4.3, U2.3 (RSTN)
SCK: J3.5, U2.20 (CLK)
SDI: J3.7, U2.18 (MOSI)
SDO: J3.6, U2.19 (MISO)
VCC1: J4.5, J4.6, J4.7, U2.5 (VCC), U2.6 (VCC), U2.7 (VCC)

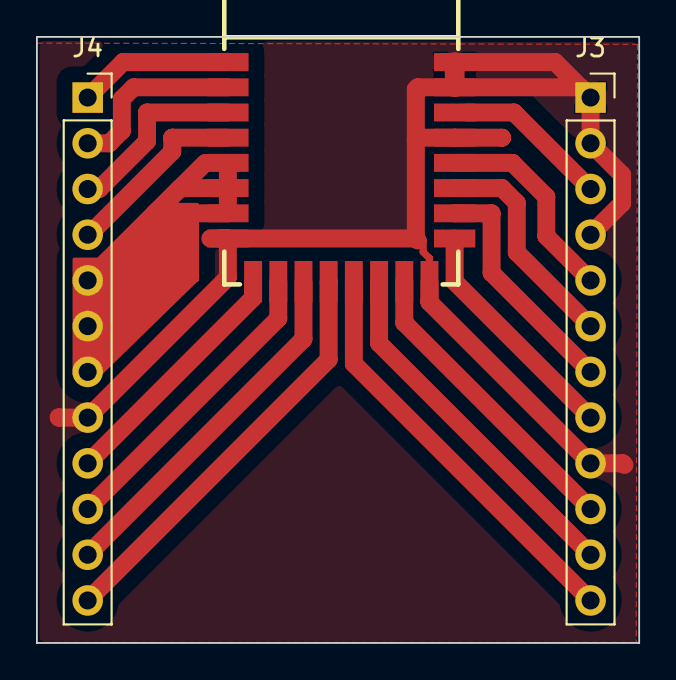
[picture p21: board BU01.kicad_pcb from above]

Board: 2 copper layers, 33.5 x 33.7 mm, 3 parts (0 on the bottom side), 18 nets.

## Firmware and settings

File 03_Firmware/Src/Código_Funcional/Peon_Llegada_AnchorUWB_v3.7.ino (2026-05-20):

/*
  PEÓN DE LLEGADA - v3.7
  ANCHOR UWB + HC-SR04 POR INTERRUPCIÓN + ESP-NOW

  Cambio principal:
  - La lógica de HC-SR04 y LED fue igualada a la del peón de salida.
  - Se usa el mismo umbral, temporización, ISR, LED con esp_timer y parpadeo de confirmación.
  - Mantiene UWB como ANCHOR y envía MSG_FINISH al cerebro.

  Hardware:
  - ESP32
  - HC-SR04: TRIG GPIO15, ECHO GPIO2
  - LED: GPIO16
  - BU01 / DW1000 como ANCHOR:
      SCK  GPIO18
      MISO GPIO19
      MOSI GPIO23
      CS   GPIO4
      RST  GPIO27
      IRQ  GPIO34
*/

#include <WiFi.h>
#include <esp_now.h>
#include <esp_wifi.h>
#include <esp_arduino_version.h>
#ifndef ESP_ARDUINO_VERSION_MAJOR
#define ESP_ARDUINO_VERSION_MAJOR 2
#endif

#include <SPI.h>
#include <math.h>
#include <string.h>
#include <esp_timer.h>
#include <driver/gpio.h>
#include "DW1000Ranging.h"

// ================= PINES =================
#define TRIG_PIN 15
#define ECHO_PIN 2
#define LED_PIN  16

#define SPI_SCK  18
#define SPI_MISO 19
#define SPI_MOSI 23
#define DW_CS    4

const uint8_t PIN_RST = 27;
const uint8_t PIN_IRQ = 34;
const uint8_t PIN_SS  = 4;

// ================= CONFIG =================
#define ESPNOW_CHANNEL 1

// Misma configuración del peón de salida.
static const float umbral_cm = 40.0f;
static const uint32_t debounce_ms = 1500;
static const uint8_t nLecturasConfirmar = 1;

static const uint32_t US_PERIOD_MS  = 25UL;
static const uint32_t US_TIMEOUT_US = 10000UL;  // suficiente para >1 m, sin bloquear

static const uint64_t LED_HALF_PERIOD_US = 80000ULL;

// Evita que el anchor sature Serial y retrase el loop.
#define DEBUG_UWB_ANCHOR 0

// MAC del CEREBRO o broadcast.
uint8_t macCerebro[] = {0x94, 0xB5, 0x55, 0x5E, 0xCC, 0x10};

// Dirección ANCHOR usada en tu código previo.
#define ANCHOR_ADD "83:17:5B:D5:A9:9A:E2:9C"

// ================= PROTOCOLO =================
enum : uint8_t {
  MSG_START    = 1,
  MSG_FINISH   = 2,
  MSG_DISTANCE = 3,
  MSG_HR       = 10,
  MSG_CMD      = 20
};

enum : uint8_t {
  SRC_PEON_SALIDA  = 1,
  SRC_PEON_LLEGADA = 2,
  SRC_BANDA_HR     = 3,
  SRC_CEREBRO      = 4
};

enum : uint8_t {
  PHASE_IDLE     = 0,
  PHASE_RUN      = 1,
  PHASE_RECOVERY = 2
};

typedef struct __attribute__((packed)) {
  uint8_t  msgType;
  uint8_t  src;
  uint16_t msgId;
  uint32_t ms;
  uint16_t raceId;
  uint8_t  athleteId;
  uint8_t  phase;
  int16_t  value1;
  int16_t  value2;
} Packet;

// ================= ESTADO =================
static uint16_t msgId = 0;
static uint32_t ultimaDet_ms = 0;
static uint8_t bajoUmbralCount = 0;

// ================= DECLARACIONES =================
void enviarFinish(float distancia_cm);
void enviarEventoPeon(float distancia_cm);

// ================= LED SIN BLOQUEO =================
/*
  LED v3.4:
  - El LED se enciende inmediatamente cuando el HC-SR04 detecta presencia bajo el umbral.
  - El parpadeo de confirmación del evento se hace con esp_timer, sin delay().
  - Al terminar el parpadeo, el LED vuelve automáticamente al estado de presencia.
*/
static esp_timer_handle_t ledTimer = nullptr;
volatile int ledTogglesRestantes = 0;
volatile bool ledEstado = false;
volatile bool ledSolicitaStop = false;
volatile bool ledBlinkActivo = false;
volatile bool ledPresenciaActiva = false;

void aplicarLedPresencia() {
  if (!ledBlinkActivo) {
    gpio_set_level((gpio_num_t)LED_PIN, ledPresenciaActiva ? 1 : 0);
    ledEstado = ledPresenciaActiva;
  }
}

void ledTimerCallback(void *arg) {
  (void)arg;

  if (ledTogglesRestantes <= 0) {
    ledBlinkActivo = false;
    ledSolicitaStop = true;
    return;
  }

  ledEstado = !ledEstado;
  gpio_set_level((gpio_num_t)LED_PIN, ledEstado ? 1 : 0);
  ledTogglesRestantes--;

  if (ledTogglesRestantes <= 0) {
    ledBlinkActivo = false;
    ledSolicitaStop = true;
  }
}

void configurarLedTimer() {
  esp_timer_create_args_t args;
  memset(&args, 0, sizeof(args));
  args.callback = &ledTimerCallback;
  args.name = "ledBlink";

  if (esp_timer_create(&args, &ledTimer) != ESP_OK) {
    Serial.println("ERROR creando timer de LED");
  }
}

void actualizarLedPresencia(bool detectado) {
  ledPresenciaActiva = detectado;
  aplicarLedPresencia();
}

void iniciarParpadeoLED(uint8_t pulsos) {
  if (ledTimer == nullptr) return;

  esp_timer_stop(ledTimer);
  ledBlinkActivo = true;
  ledSolicitaStop = false;
  ledEstado = false;
  gpio_set_level((gpio_num_t)LED_PIN, 0);
  ledTogglesRestantes = pulsos * 2;
  esp_timer_start_periodic(ledTimer, LED_HALF_PERIOD_US);
}

void servicioLED() {
  if (ledSolicitaStop && ledTimer != nullptr) {
    ledSolicitaStop = false;
    esp_timer_stop(ledTimer);
    aplicarLedPresencia();
  }
}

// ================= ULTRASONIDO POR INTERRUPCIÓN =================
/*
  HC-SR04 v3.4:
  - ECHO se mide por interrupción.
  - TRIG usa solo un pulso bloqueante de 10 us, despreciable frente al resto del sistema.
  - No usa pulseIn(), delay() ni pausas por calibración UWB.
  - Misma lógica en salida y llegada.
*/
volatile uint32_t usEchoInicioUs = 0;
volatile uint32_t usDuracionUs = 0;
volatile uint32_t usUltimoDisparoUs = 0;
volatile bool usMedicionLista = false;
volatile bool usEsperandoEco = false;
volatile bool usEchoAlto = false;

static uint32_t usUltimoTriggerMs = 0;

void IRAM_ATTR isrEchoUltrasonido() {
  uint32_t ahora = micros();
  int nivel = gpio_get_level((gpio_num_t)ECHO_PIN);

  if (nivel) {
    usEchoInicioUs = ahora;
    usEchoAlto = true;
  } else if (usEchoAlto) {
    usDuracionUs = ahora - usEchoInicioUs;
    usMedicionLista = true;
    usEchoAlto = false;
    usEsperandoEco = false;
  }
}

void reiniciarEstadoUltrasonido() {
  noInterrupts();
  usMedicionLista = false;
  usEsperandoEco = false;
  usEchoAlto = false;
  interrupts();
  digitalWrite(TRIG_PIN, LOW);
}

void dispararUltrasonido() {
  noInterrupts();
  usMedicionLista = false;
  usEchoAlto = false;
  usEsperandoEco = true;
  interrupts();

  digitalWrite(TRIG_PIN, LOW);
  delayMicroseconds(2);
  digitalWrite(TRIG_PIN, HIGH);
  delayMicroseconds(10);
  digitalWrite(TRIG_PIN, LOW);

  noInterrupts();
  usUltimoDisparoUs = micros();
  interrupts();
}

void servicioTriggerUltrasonido() {
  bool esperando;
  noInterrupts();
  esperando = usEsperandoEco;
  interrupts();

  if (!esperando && (millis() - usUltimoTriggerMs >= US_PERIOD_MS)) {
    usUltimoTriggerMs = millis();
    dispararUltrasonido();
  }
}

bool obtenerMedicionUltrasonido(float &distancia_cm) {
  bool lista = false;
  bool timeout = false;
  uint32_t duracion = 0;

  noInterrupts();
  if (usMedicionLista) {
    lista = true;
    duracion = usDuracionUs;
    usMedicionLista = false;
  } else if (usEsperandoEco && (uint32_t)(micros() - usUltimoDisparoUs) > US_TIMEOUT_US) {
    timeout = true;
    usEsperandoEco = false;
    usEchoAlto = false;
  }
  interrupts();

  if (lista) {
    if (duracion == 0 || duracion > US_TIMEOUT_US) {
      distancia_cm = -1.0f;
    } else {
      distancia_cm = (duracion * 0.0343f) / 2.0f;
    }
    return true;
  }

  if (timeout) {
    distancia_cm = -1.0f;
    return true;
  }

  return false;
}

void procesarMedicionUltrasonido(float d) {
  bool detectado = (d > 0 && d <= umbral_cm);
  actualizarLedPresencia(detectado);

  if (detectado) {
    bajoUmbralCount++;
  } else {
    bajoUmbralCount = 0;
  }

  uint32_t ahora = millis();
  if (bajoUmbralCount >= nLecturasConfirmar) {
    if (ahora - ultimaDet_ms > debounce_ms) {
      ultimaDet_ms = ahora;
      bajoUmbralCount = 0;
      enviarEventoPeon(d);
    }
  }
}

void configurarUltrasonido() {
  pinMode(TRIG_PIN, OUTPUT);
  pinMode(ECHO_PIN, INPUT);
  digitalWrite(TRIG_PIN, LOW);
  attachInterrupt(digitalPinToInterrupt(ECHO_PIN), isrEchoUltrasonido, CHANGE);
}

// ================= ESPNOW =================
#if ESP_ARDUINO_VERSION_MAJOR >= 3
static void onDataSent(const wifi_tx_info_t *info, esp_now_send_status_t status) {
  (void)info;
#else
static void onDataSent(const uint8_t *mac_addr, esp_now_send_status_t status) {
  (void)mac_addr;
#endif
  Serial.print("ESP-NOW FINISH send: ");
  Serial.println(status == ESP_NOW_SEND_SUCCESS ? "OK" : "FAIL");
}

void enviarFinish(float distancia_cm) {
  Packet p{};
  p.msgType = MSG_FINISH;
  p.src = SRC_PEON_LLEGADA;
  p.msgId = ++msgId;
  p.ms = millis();
  p.phase = PHASE_IDLE;
  p.value1 = (int16_t)lroundf(distancia_cm * 10.0f); // cm*10 del HC-SR04
  p.value2 = 0;

  for (int i = 0; i < 3; i++) {
    esp_now_send(macCerebro, (uint8_t*)&p, sizeof(p));
  }

  iniciarParpadeoLED(3);

  Serial.print(">>> FINISH enviado. Dist HC-SR04=");
  Serial.print(distancia_cm, 1);
  Serial.println(" cm");
}

void enviarEventoPeon(float distancia_cm) {
  enviarFinish(distancia_cm);
}

void configurarEspNow() {
  WiFi.mode(WIFI_STA);
  WiFi.disconnect();
  delay(100);
  esp_wifi_set_channel(ESPNOW_CHANNEL, WIFI_SECOND_CHAN_NONE);

  if (esp_now_init() != ESP_OK) {
    Serial.println("ERROR: esp_now_init()");
    while (true) delay(1000);
  }

  esp_now_register_send_cb(onDataSent);

  esp_now_peer_info_t peer{};
  memcpy(peer.peer_addr, macCerebro, 6);
  peer.channel = ESPNOW_CHANNEL;
  peer.ifidx = WIFI_IF_STA;
  peer.encrypt = false;

  if (!esp_now_is_peer_exist(macCerebro)) {
    if (esp_now_add_peer(&peer) != ESP_OK) {
      Serial.println("ERROR: esp_now_add_peer(macCerebro)");
      while (true) delay(1000);
    }
  }
}

// ================= UWB ANCHOR =================
void newRange() {
#if DEBUG_UWB_ANCHOR
  Serial.print("UWB from: ");
  Serial.print(DW1000Ranging.getDistantDevice()->getShortAddress(), HEX);
  Serial.print(" Range: ");
  Serial.print(DW1000Ranging.getDistantDevice()->getRange());
  Serial.print(" m RX: ");
  Serial.print(DW1000Ranging.getDistantDevice()->getRXPower());
  Serial.println(" dBm");
#endif
}

void newBlink(DW1000Device *device) {
#if DEBUG_UWB_ANCHOR
  Serial.print("UWB blink, device added. short: ");
  Serial.println(device->getShortAddress(), HEX);
#else
  (void)device;
#endif
}

void inactiveDevice(DW1000Device *device) {
#if DEBUG_UWB_ANCHOR
  Serial.print("UWB dispositivo inactivo: ");
  Serial.println(device->getShortAddress(), HEX);
#else
  (void)device;
#endif
}

void configurarUWB() {
  SPI.begin(SPI_SCK, SPI_MISO, SPI_MOSI);
  DW1000Ranging.initCommunication(PIN_RST, PIN_SS, PIN_IRQ);
  DW1000Ranging.attachNewRange(newRange);
  DW1000Ranging.attachBlinkDevice(newBlink);
  DW1000Ranging.attachInactiveDevice(inactiveDevice);
  DW1000Ranging.startAsAnchor(ANCHOR_ADD, DW1000.MODE_SHORTDATA_FAST_LOWPOWER, false);
}

// ================= SETUP / LOOP =================
void setup() {
  Serial.begin(115200);
  delay(500);

  pinMode(LED_PIN, OUTPUT);
  digitalWrite(LED_PIN, LOW);
  configurarLedTimer();

  configurarUltrasonido();
  configurarEspNow();
  configurarUWB();

  Serial.println();
  Serial.println("PEÓN DE LLEGADA - v3.7: MISMA LÓGICA DE ULTRASONIDO/LED QUE PEÓN DE SALIDA + ANCHOR UWB");
  Serial.print("MAC local: ");
  Serial.println(WiFi.macAddress());
  Serial.print("Canal ESPNOW: ");
  Serial.println(ESPNOW_CHANNEL);
  Serial.println("Listo.");
}

void loop() {
  DW1000Ranging.loop();
  servicioLED();
  servicioTriggerUltrasonido();

  float d = -1.0f;
  if (obtenerMedicionUltrasonido(d)) {
    procesarMedicionUltrasonido(d);
  }
}

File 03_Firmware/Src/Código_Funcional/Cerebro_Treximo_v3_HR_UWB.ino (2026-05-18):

/*
  CEREBRO / CRONÓMETRO TREXIMO - v3 HR + UWB
  ESP32 + TFT ST7735 + RTC DS3231 + ESP-NOW

  Implementa:
  - Protocolo ESP-NOW unificado.
  - Recepción START / FINISH desde peones.
  - Recepción BPM desde módulo MAX30102 por ESP-NOW.
  - Comando broadcast de fase: IDLE / RUN / RECOVERY.
  - Calibración de distancia UWB con STOP + RESET durante 2 s.
  - Comando broadcast de calibración de distancia.
  - Recepción de distancia promedio desde peón de salida/tag UWB.
  - Distancia guardada en memoria flash con Preferences.
  - Velocidad mostrada en m/s.

  Botones:
  - START: inicia carrera manual.
  - STOP: detiene carrera manual.
  - RESET: reinicia cronómetro.
  - STOP + RESET por 2 s: calibra distancia UWB, solo si el cronómetro está detenido.
*/

#include <WiFi.h>
#include <esp_now.h>
#include <esp_wifi.h>
#include <esp_arduino_version.h>
#ifndef ESP_ARDUINO_VERSION_MAJOR
#define ESP_ARDUINO_VERSION_MAJOR 2
#endif

#include <Wire.h>
#include "RTClib.h"
#include <Preferences.h>

#include <Adafruit_GFX.h>
#include <Adafruit_ST7735.h>
#include <SPI.h>
#include <Fonts/FreeSansBold18pt7b.h>
#include <Fonts/FreeSansBold12pt7b.h>
#include <Fonts/FreeSans9pt7b.h>

// ================= PINES =================
#define TFT_CS     5
#define TFT_RST    4
#define TFT_DC     2

#define BTN_START 12
#define BTN_STOP  13
#define BTN_RESET 14

// ================= CONFIG =================
#define ESPNOW_CHANNEL 1
#define RECOVERY_MS    60000UL
#define HR_TIMEOUT_MS  3500UL
#define CAL_TIMEOUT_MS 12000UL

Adafruit_ST7735 tft = Adafruit_ST7735(TFT_CS, TFT_DC, TFT_RST);
RTC_DS3231 rtc;
Preferences prefs;

#define BG_COLOR    tft.color565(10, 10, 15)
#define TIME_COLOR  ST77XX_WHITE
#define VEL_COLOR   tft.color565(0, 255, 255)
#define BPM_COLOR   ST77XX_WHITE
#define GREY_TEXT   tft.color565(120, 120, 130)

// ================= PROTOCOLO ESPNOW =================
enum : uint8_t {
  MSG_START    = 1,
  MSG_FINISH   = 2,
  MSG_DISTANCE = 3,
  MSG_HR       = 10,
  MSG_CMD      = 20
};

enum : uint8_t {
  SRC_PEON_SALIDA  = 1,
  SRC_PEON_LLEGADA = 2,
  SRC_BANDA_HR     = 3,
  SRC_CEREBRO      = 4
};

enum : uint8_t {
  PHASE_IDLE     = 0,
  PHASE_RUN      = 1,
  PHASE_RECOVERY = 2
};

enum : int16_t {
  CMD_SET_PHASE          = 1,
  CMD_CALIBRATE_DISTANCE = 2
};

typedef struct __attribute__((packed)) {
  uint8_t  msgType;
  uint8_t  src;
  uint16_t msgId;
  uint32_t ms;
  uint16_t raceId;
  uint8_t  athleteId;
  uint8_t  phase;
  int16_t  value1;
  int16_t  value2;
} Packet;

uint8_t macBroadcast[] = {0xFF, 0xFF, 0xFF, 0xFF, 0xFF, 0xFF};
uint16_t msgIdLocal = 0;
uint16_t raceIdActual = 0;

// ================= ESTADO CRONÓMETRO =================
DateTime horaInicio;
DateTime horaFin;

unsigned long tiempoInicio = 0;
unsigned long tiempoPausado = 0;
bool cronometroActivo = false;

// ================= ESTADO FASE / RECUPERACIÓN =================
uint8_t faseActual = PHASE_IDLE;
uint32_t tInicioRecuperacion = 0;

// ================= BPM =================
int bpm = -1;
uint32_t tUltimoBpm = 0;

// ================= DISTANCIA / VELOCIDAD =================
float distancia_m = 0.0f;
bool distanciaValida = false;
float velocidad_ms = 0.0f;
bool velocidadValida = false;

bool esperandoDistancia = false;
uint32_t tInicioCalibracion = 0;

// Eventos recibidos por ESP-NOW.
// El callback solo marca banderas; la lógica pesada se ejecuta en loop().
volatile bool evtStart = false;
volatile bool evtFinish = false;
volatile bool evtHr = false;
volatile bool evtDistance = false;
volatile int16_t evtHrValue = -1;
volatile int16_t evtDistanceValue = -1;
volatile int16_t evtDistanceSamples = 0;

// ================= UI =================
bool overlayActivo = false;
uint32_t overlayHasta = 0;

String oldBpmTexto = "";
String oldVelTexto = "";
unsigned long oldTiempoMs = 999999999UL;

// ================= DECLARACIONES =================
void dibujarInterfazBase();
void dibujarTiempoMs(unsigned long actual);
void limpiarTiempo();
void actualizarCronometro();
void actualizarSensores(bool forzar = false);
void pantallaCarga();
void mostrarOverlay(const char* linea1, const char* linea2 = nullptr, uint32_t duracionMs = 0);
void cerrarOverlaySiVence();
void enviarComando(int16_t comando, uint8_t phase, uint8_t repeticiones = 2);
void cambiarFase(uint8_t nuevaFase);
void iniciarCronometro();
void detenerCronometro();
void resetSistema();
void iniciarCalibracionDistancia();
void manejarTimeoutCalibracion();
void manejarRecuperacion();
void actualizarVelocidad();
void manejarBotones();
void procesarEventosEspNow();

// ================= ESPNOW =================
static void copiarPacket(Packet &p, const uint8_t *data, int len) {
  memset(&p, 0, sizeof(p));
  if (len <= 0) return;
  memcpy(&p, data, min((int)sizeof(Packet), len));
}

#if ESP_ARDUINO_VERSION_MAJOR >= 3
void OnDataRecv(const esp_now_recv_info_t *info, const uint8_t *data, int len) {
  (void)info;
#else
void OnDataRecv(const uint8_t *mac, const uint8_t *data, int len) {
  (void)mac;
#endif
  Packet p;
  copiarPacket(p, data, len);

  switch (p.msgType) {
    case MSG_START:
      evtStart = true;
      break;

    case MSG_FINISH:
      evtFinish = true;
      break;

    case MSG_HR:
      evtHrValue = p.value1;
      evtHr = true;
      break;

    case MSG_DISTANCE:
      evtDistanceValue = p.value1;
      evtDistanceSamples = p.value2;
      evtDistance = true;
      break;
  }
}

void procesarEventosEspNow() {
  if (evtStart) {
    evtStart = false;
    iniciarCronometro();
  }

  if (evtFinish) {
    evtFinish = false;
    detenerCronometro();
  }

  if (evtHr) {
    int16_t valor = evtHrValue;
    evtHr = false;

    if ((faseActual == PHASE_RUN || faseActual == PHASE_RECOVERY) && valor > 0) {
      bpm = valor;
      tUltimoBpm = millis();
    } else {
      bpm = -1;
      tUltimoBpm = 0;
    }
  }

  if (evtDistance) {
    int16_t valor = evtDistanceValue;
    int16_t muestras = evtDistanceSamples;
    evtDistance = false;

    // Ignorar duplicados tardíos si ya no estamos esperando calibración.
    if (!esperandoDistancia) return;

    esperandoDistancia = false;
    if (valor > 0) {
      distancia_m = valor / 100.0f;   // value1 viene en centímetros
      distanciaValida = true;
      prefs.putFloat("dist_m", distancia_m);

      char linea[24];
      snprintf(linea, sizeof(linea), "Dist: %.2f m", distancia_m);
      mostrarOverlay(linea, nullptr, 2500);

      Serial.print("Distancia calibrada: ");
      Serial.print(distancia_m, 2);
      Serial.print(" m  muestras=");
      Serial.println(muestras);
    } else {
      mostrarOverlay("ERROR UWB", nullptr, 2500);
      Serial.print("ERROR UWB: calibración sin distancia válida. muestras=");
      Serial.println(muestras);
    }
  }
}
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

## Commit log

2026-02-23 Enhance README with project details and objectives
    Added detailed project description, objectives, architecture, and current status.
2026-02-23 Esquematico de Altium
    Conexiones del semestre pasado realizadas en Altium
    [Sheet1.SchDoc]
2026-02-23 Readme de la gestión del proyecto
    Added detailed documentation for project management, including meeting minutes, BOM, and timelines.
2026-02-23 Enhance README with hardware design details
    Added detailed documentation about the hardware design, architecture, and folder structure for the ESP32-based distributed system.
2026-02-23 Create Herramientas de Auditoria y Planeación
2026-02-23 Herramientas de Auditoria y Planeación
2026-02-23 Cronograma de actividades
2026-02-25 Prueba Inicial de la pantalla
    Se hace la primer prueba de la pantalla para el cronómetro y así mostrar que funciona con un código simple
2026-02-25 Alternativa 1 Interfaz del cronómetro
    En este código de arduino se aloja una de las dos alternativas que se va a tener para mostrar los datos en la pantalla del cronómetro
2026-02-26 Segunda Alternativa para cronómetro
    En este código se presenta la segunda alternativa para la interfaz del cronómetro
2026-03-02 Codigo de cronometro basico
    Se tiene una primer visión del cronometro funcional
2026-03-16 Codigo para peones basico
    En este código se aloja el funcionamiento básico del cerebro del sistema al que se quiere llegar
2026-03-16 Código Cerebro con RTC
    Código funcional para el cerebro con un RTC para ver las horas de llegada y salida del atleta
2026-04-13 Create Bill Of Materials
2026-04-13 Add Bill Of Materials section to README
    Added Bill Of Materials (BOM) section detailing components for the system, including cost estimates and functions for each item.
2026-04-13 Rename 01_Gestion/Bill Of Materials to 01_Gestion/BOM/Bill Of Materials
2026-04-13 Rename 01_Gestion/Cronograma de actividades to 01_Gestion/Planeación/Cronograma de actividades
2026-04-13 Reloj de tiempo real DS3231
2026-04-13 Led Rojo
2026-04-25 Add README for BU01 PCB module
2026-04-26 Implement KY-039 pulse sensor functionality
    Refactor code to implement KY-039 pulse sensor functionality, including reading analog values, detecting pulses, and calculating BPM. Removed ultrasonic sensor code and added necessary configurations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
2026-04-27 PCB del eslabon básico
    En este .zip está alojada la primer versión del diseño de PCB para la implementación básica de los eslabones, es decir, el sistema que está compuesto por ESP32, un led y el ultrasonido; faltando la i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
2026-05-02 Add Peón de Llegada functionality for distance sensing
    This file implements the Peón de Llegada functionality for an ESP32 device using HC-SR04 and ESP-NOW to send distance measurements.
2026-05-02 Change LED GPIO pin from 18 to 4
2026-05-02 Código actualizado del peón de salida básico
2026-05-03 Change LED_PIN definition from 18 to 4
2026-05-03 Add Test_UWB_ANCHOR_V2.ino file
    Cambio de ShortRange a LongRange en los UWB
    [Test_UWB_ANCHOR_V2.ino]
2026-05-03 Implement optimized DW1000 TAG features
    Optimización de código DW1000 para mayor distancia de lectura
2026-05-04 Informe de Avance Técnico
2026-05-11 Archivos de esquemático y PCB para el eslabón completo
    Se encuentra alojado el archivo gerber de salida para poder hacer la impresión de la placa, a demás se recomienda hacerle espejo ya que hace parte de la capa bottom cupper
    [Esclavo.kicad_pcb, Esclavo.kicad_sch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]
2026-05-13 Create AlternativaPantalla3.0.ino
    Código para visualización de distancia en la TFT
2026-05-13 Create CodigoFinalPantalla.ino
    Este es el código final para la interfaz física del cronómetro para visualización de las variables tales como tiempo, frecuencia cardiaca, velocidad y distancia
2026-05-14 Archivos STL de peón y Cronometro
    Estos son los archivos para la impresión 3D iniciales.
    [CronometroV2.stl, PeonesMiguelTorresSTL.stl]
2026-05-14 Código de peones salida y llegada
    Códigos con transmisión adecuada al cerebro. Es posible añadir correcciones en activación del led
2026-05-15 Súbida de todo el sistema en flutter y android studio
    En este commit se sube todo el sistema de la interfaz con funcionamiento simulado y sin conexión a los datos del ESP32
2026-05-15 Eliminación Archivo de proyecto no relevante
2026-05-16 Versión corregida de archivos 3D
    Se realizaron algunas cejitas para ubicar los pulsadores, se cambió la ubicación de los puertos de carga de los peones para que queden a la altura de las baterías, se corrigió el orificio de las baterías y se añade el LED bajo los ultrasonidos
    [Cronometro_V2.stl, Peones_V2.stl]
2026-05-18 Cambiar ubicación
    Alternativas de pantalla pasan a pruebas individuales, Cronometros básicos pasan a pruebas individuales
2026-05-18 Ultima versión
    Se añade el cerebro (Cronometro) y peón de llegada y se descarta la banda momentaneamente
2026-05-20 Reorganización de carpetas
